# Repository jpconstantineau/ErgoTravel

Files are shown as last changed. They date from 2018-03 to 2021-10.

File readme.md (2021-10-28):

ErgoTravel
====

ErgoTravel

A split ergo 4x6 keyboard with 2 or 3 thumb keys and extra inner macro keys designed by Pierre Constantineau. [More info on the GitHub Repo](https://github.com/jpconstantineau/ErgoTravel).

**Status** The ErgoTravel is currently well developed and has the following versions:

| Version | Description |
| --- | --- |
| ErgoTravel 1.03 | Supports MX & Alps switches  |
| ErgoTravel 1.1 | Supports MX switches  |
| ErgoTravelLight 1.0 | Supports Choc Low Profile switches  |
| ErgoTravelLight 2.0 | Supports Choc Low Profile switches and has In Switch LEDs  |

Version 1.1 was created to eliminate the "Too Many Slots Additional Cost from JLCPCB"

Keyboard Maintainer: [/u/jpconstantineau](https://github.com/jpconstantineau)  

Hardware Supported: Pro Micro (ATmega32U4) 

Hardware Availability: [Group Buys](https://keyboards.jpconstantineau.com/) or order your own [yourself](OrderingInstructions.md)



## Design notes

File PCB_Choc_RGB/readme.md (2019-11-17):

2.00: initial prototype
2.01: updated location of vias and traces near standoffs. Also updated build instructions

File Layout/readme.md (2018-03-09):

ErgoTravel
====

ErgoTravel

Use the txt files to load in KLE or swillkb.

[Keyboard Layout Editor](http://www.keyboard-layout-editor.com)
[Plate Generator](http://builder.swillkb.com/)

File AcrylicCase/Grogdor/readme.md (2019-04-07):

Work in progress, currently prototyping for fit/tolerances, stackup, fasteners, manufacturing, etc.

"TENTED" layers are currently out of sync with bluemicro holes

ToDo:
- revisit hipro design, small pieces are weak and can break off, are they really needed?
- tenting is wobbly, boo
- put engrave near the top, so job doesn't have to wait/scroll all the way down to it... saves like 20sec per plate
- use "plated" lines inside "cutout" for everything, not sharp duplicate corners (but check corner @ TRRS jack for PCB clearance) - no longer relevant because we're not making internal  plates of the leftover material, however rounded corners would likely put less strain on the material
- 2ustabs engraves need to happen in one shot for proper material removal, not needlessly+time spread across workpieces; how to ensure that? - because of heat buildup for removing material, if the laser traverses the whole sheet it doesn't happen properly. Engraves are set to Y axis, so just spread the black fills across the plate as needed.
- fillet sharp outside bottom corner where hand sits - doesn't look/feel right
- *** join all polylines + overkill ***
- figure out why Corel Draw puts a red outline around the black hatch engrave for 2ustabs - just doesn't handle AutoCAD hatches, have to cleanup lines and fill color manually for .cdr file
- figure out how layers/groups/viewports work for easier viewing, exporting, etc. - really need a CAD pro for some tricks to do this easier...

ToTry:
- 6mm hipro with blind inserts
- consider 9mm mid (no bonus internal plate on this one, segment it) with optional 3mm addon or other stackups
- spread out the two tenting bolts (trrs to top? bottom to corner or at least closer?), make single tenting screw more central to balance point
- reorganize layers into nested groups to tame the chaos
- a few "yellow" surface finish cuts can be sped up "red" like inside of "cutouts" etc
- colors? something other than clear/white/smoke scraps
- experiment with "internal pcb" screws through the top plate, for strength
- experiment with segmented midlayer(s), saves significant material, easier/stronger to ship
- see how long it takes the Rabbit, what the finish/kerf/accuracy is like...
- ditch the single foot and replace with a strip of rubber/neoprene edge for flat-f/b tent
- furniture swivel/levelling feet for tenting? do these come small enough? what's the grip surface like?
- alu rod, ball one end on the lathe, trim/thread to taste, goes into nut pressed into case, polish/paint/shrink tube
- check model shop for "aluminum pillow balls" and other small suspension bits for ^
- cool crane outriggers, non-swivel, flip-out, fold out, r/a inserts, diagonal slide out
- angled acrylic? edge clip ins for tenting?
- m3 thumbscrews into the side of 9-12mm midlayer to hold legs, t-slots into segments or flip em (in a jig?) and engrave nuthole, cut bolthole
- nice long radius ark at the bottom of the pcb+case where your hand goes, or maybe just in the plate/case and some neoprene...

ToDFM:
- air assist OFF?? for cleaner edges per https://www.troteclaser.com/fileadmin/content/images/News/EN_US/2016-07-crown-trophy/Handbook-for-engravers.pdf - smoke/gas made it worse, slowing down the cut and upping the Hz helped the edge finish a lot
- figure out optimal sheet/plate/bed size, important for cut layout, production runs, colors, etc. either on the Trotec or external - consider logistics of organizing pieces, turns out tossing scraps around was easier file/cut/pack-wise than keeping track of odd pieces, making extra files, etc
- shared cutlines on sheet/plate layouts - probably only worth it if paying per laser minute, even then may not be that great with these shapes

ToDon't:
- (N/A due to 3mm layers stackup) with noticeable kerf on the 9mm single midlayer, do we want to kick the bottom layer out 0.?mm to eliminate slight edge where they meet?
- (using 2ustabs as universal plate) hipro, 1u1u
- re-import "construction" layer from previous drawing
- (there's not) revisit 1u1u hipro altho there's probably not enough space between the keys to make another/non-universal SKU worthwhile

ToDone:
- switch to MX+Alps cutouts, they're also openable!! ***
- 2U/1U Combined stabilizer hole ***
- 2U Stab Hole stepped engrave over bar, how will other stabs fit? make sure 1u1u and 2u keycaps cover clear engrave surface finish *
- separate keyswitch/1u1u/2ustab layers
- Design Mids/Bottom with Tenting Holes (as extra layer) **
- cutline ordering with colors, to spread/prevent offgassing thumps and make better use of traverse *
- change layer colors to reorder cutting per Trotec default
- re-import "PCB" layer from previous drawing
- Design Mid Layer/Bottom Plate for Wireless ErgoTravel (No TRRS connector) (as layer?) *
- wiggle reset button hole over just a wee bit
- Insert Small Bottom Plate in Mid layers **
- Insert Top Plate in Mid layers **
- ^^ check screwhole positions and size
- hipro, 2ustab *
- ^^ check keycap clearances
- try lower power+speed and/or higher Hz for cleaner edge finish *

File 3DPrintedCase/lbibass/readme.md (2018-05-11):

here's my design for a printed case for the ergotravel. Note that the design could change as I make revisions to it. I will update the names as that happens. I will also document the changes in the PR.

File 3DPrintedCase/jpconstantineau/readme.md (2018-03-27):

ErgoTravel
====

To Do:

Design of a 3D printed Case in 4 parts

Top/Bottom Left
Top/Bottom Right

Similar design to Let's Split Case [on Thingiverse](https://www.thingiverse.com/thing:2626039)

- It's angled 
- It's very close to the size of the PCB
- The back of the case protects the connectors.

Ideally generated with OpenScad (to make the design open source using free tools - just like the PCB)

Production Files to be stored in STL folder once completed so that people don't need to "compile" the design into a file that can be produced.

Note: dxf files are for reference. The orientation of the 1U thumb switches are not right

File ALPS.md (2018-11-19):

# Considerations when Using Alps-Style switches

If you're planning on putting ALPS-style switches in your ergotravel, there are a couple things you'll have to consider.

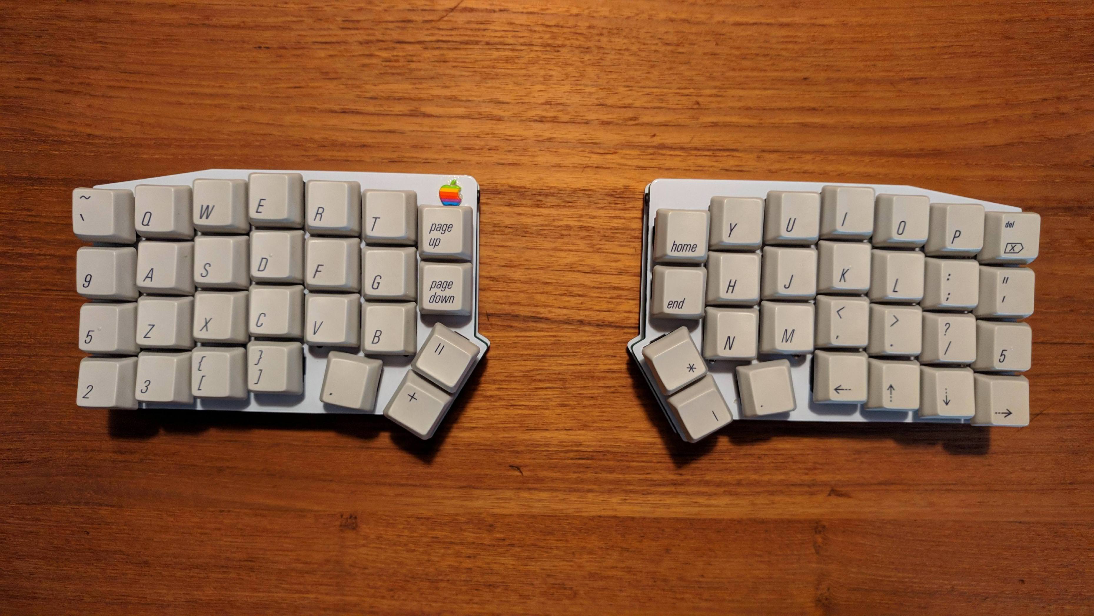
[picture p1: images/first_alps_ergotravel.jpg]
A completed Alps build.

*A completed Alps build.*

Currently, the plates only allow for 2 1u keycaps in the thumbs. As such, you won't be able to put a 2u keycap in there.

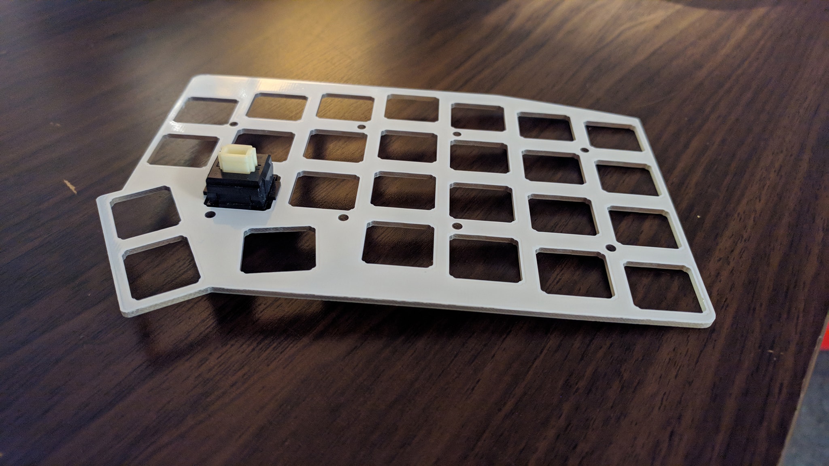
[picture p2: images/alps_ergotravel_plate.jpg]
Alps ergotravel plate.

*Alps ergotravel plate.*

Because the switches are ever-so-slightly wider than their MX counterparts, you'll have to file down the bottom left and right corners of the switches that sit on top of the ProMicro. This will allow the switch to sit flush upon the PCB. This is also true of the Iris and indeed any other keyboard that has switches right on top of the ProMicro.

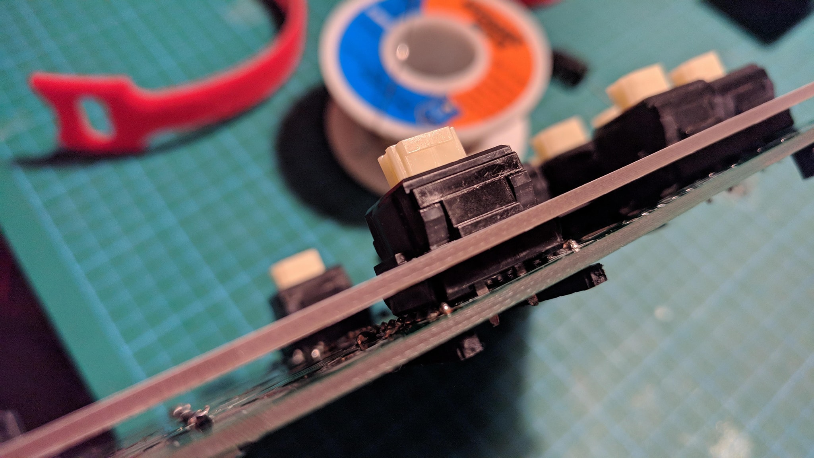
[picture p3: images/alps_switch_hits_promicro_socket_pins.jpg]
Alps switch resting upon promicro socket pins.

*Alps switch resting upon promicro socket pins.*

You may have to use similar methods to accomodate diode leads in rare occurences. Try to ensure that all switches sit flush prior to soldering them.

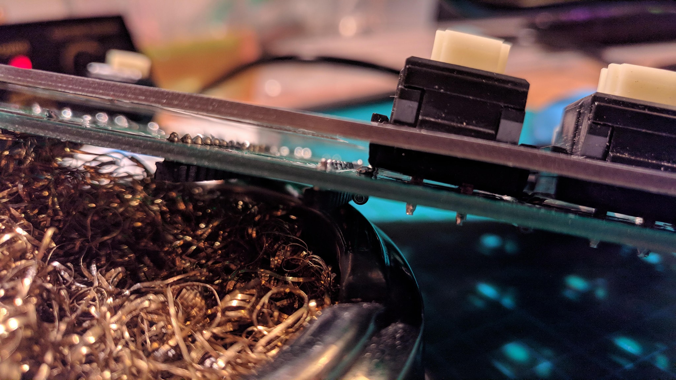
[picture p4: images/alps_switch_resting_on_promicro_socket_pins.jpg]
Alps switch resting upon diode leads.

*Alps switch resting upon diode leads.*

To do so, simply place a file on the table and run the corner of the switch along it at a 45-degree angle as pictured below.

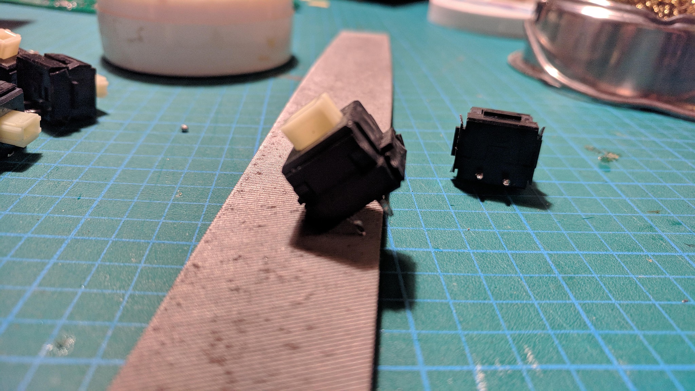
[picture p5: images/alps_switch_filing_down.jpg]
Filing down the corner of an Alps switch.


Continue with the other bottom side of the switch until it sits flush on the PCB. This doesn't take much and shouldn't go through the housing at all.

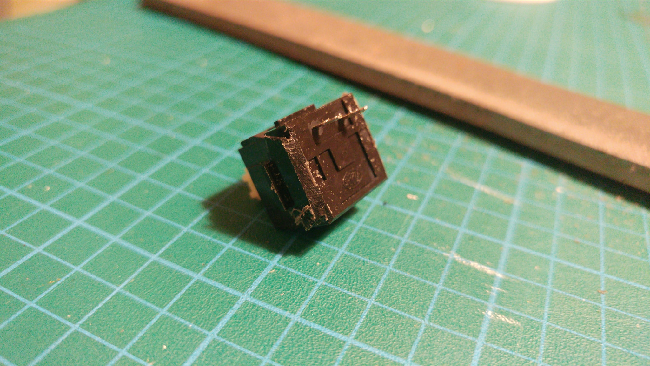
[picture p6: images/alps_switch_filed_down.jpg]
A corner of an alps switch after filing it down.


When finished, the switches should sit flush against the PCB, the filed down corners now accomodating the promicro's sockets.

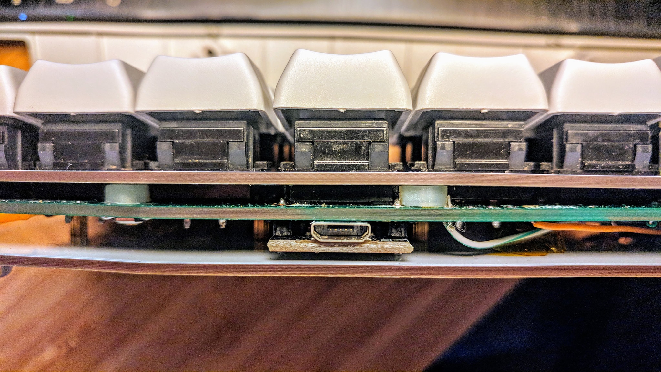
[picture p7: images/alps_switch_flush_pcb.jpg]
Alps switch sitting flush on top of promicro.

*Alps switch sitting flush on top of promicro.*

You'll also likely have to clip the leads of the switches that sit on top of the pro micro if you're using low-profile sockets or no sockets. These too may make contact with the promicro if left at their full length.

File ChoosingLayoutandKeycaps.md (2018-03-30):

# Choosing the layout of your Ergotravel

---

There are 3 options for the layout of the ErgoTravel.  They account for 4 unique configurations.

## Option 1: 2x 2U Thumb Keys

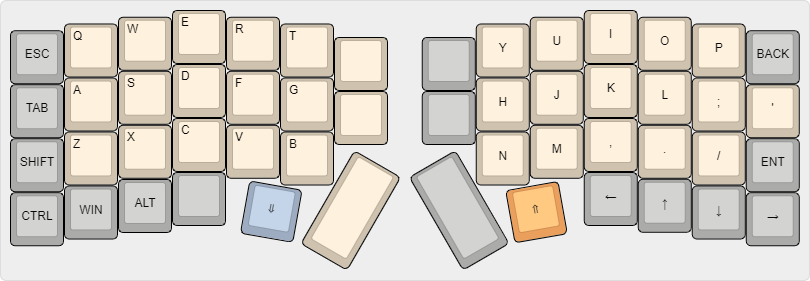
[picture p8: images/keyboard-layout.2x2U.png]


## Option 2: 1x 2U and 2x 1U Thumb Keys
With this option the 2U key will be on the left or right with the 2x 1U keys on  the other side.
Note that some Planck Keycap kits will not have enough 1U keys to support this layout.  The 4 1U macro keys on the inner columns may be left out.

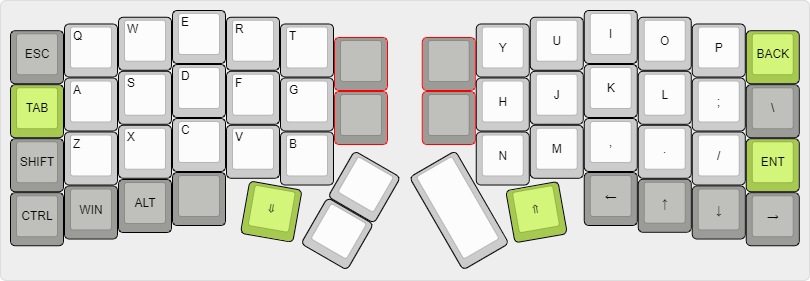
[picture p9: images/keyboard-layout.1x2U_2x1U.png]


## Option 3: 4x 1U Thumb Keys
With this option, you will only use 1U keys and will not require stabilizers. 
Note that many of the Planck Keycap kits will not have enough 1U keys to support this layout.  Only the larger kits may be able to support this layout.

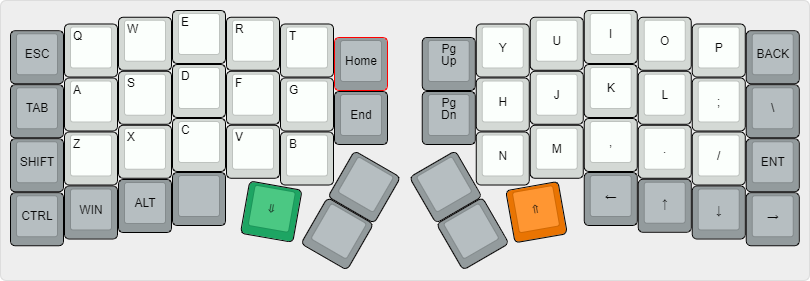
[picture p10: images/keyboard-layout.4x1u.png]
4x1u


# Choosing the keycaps for your Ergotravel

If you have pre-selected your layout, you will want to find a keycap kit that has enough keys for your layout.  Below are examples of kits that could be used for the supported layouts.  You may have to compromise on color or keycap profile.

## Option 1: 2x 2U Thumb Keys

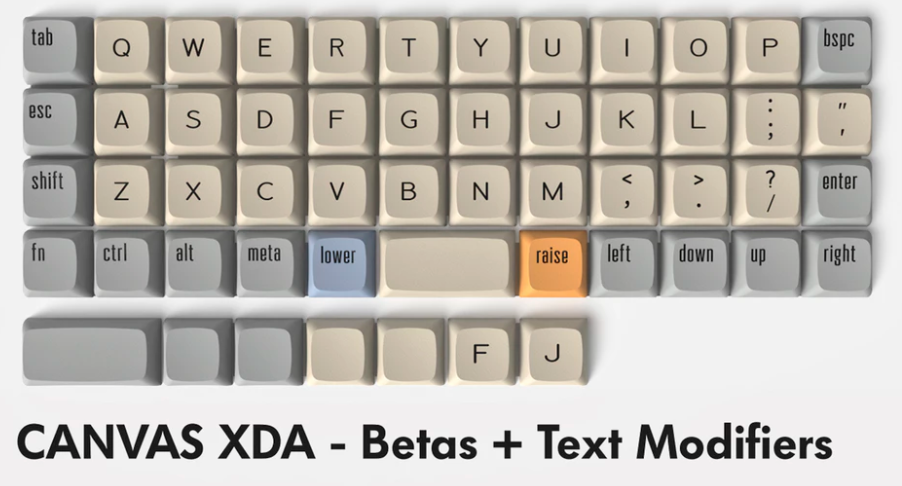
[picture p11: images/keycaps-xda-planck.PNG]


## Option 2: 1x 2U and 2x 1U Thumb Keys

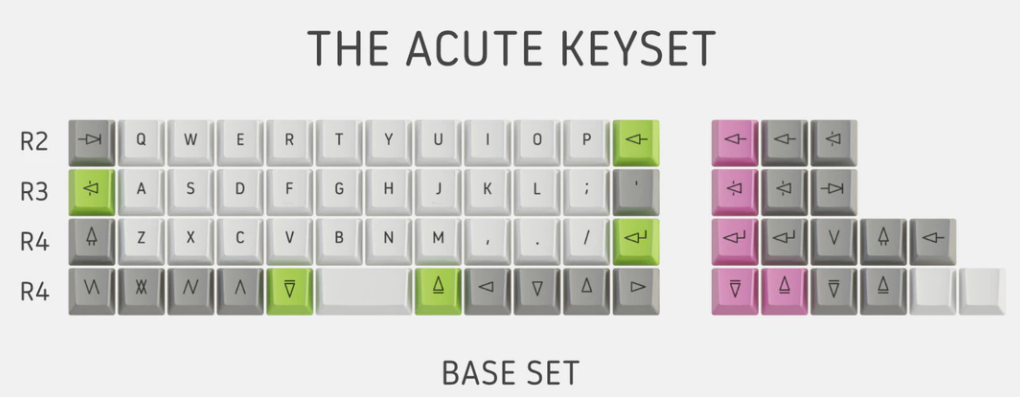
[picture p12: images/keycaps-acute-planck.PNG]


## Option 3: 4x 1U Thumb Keys

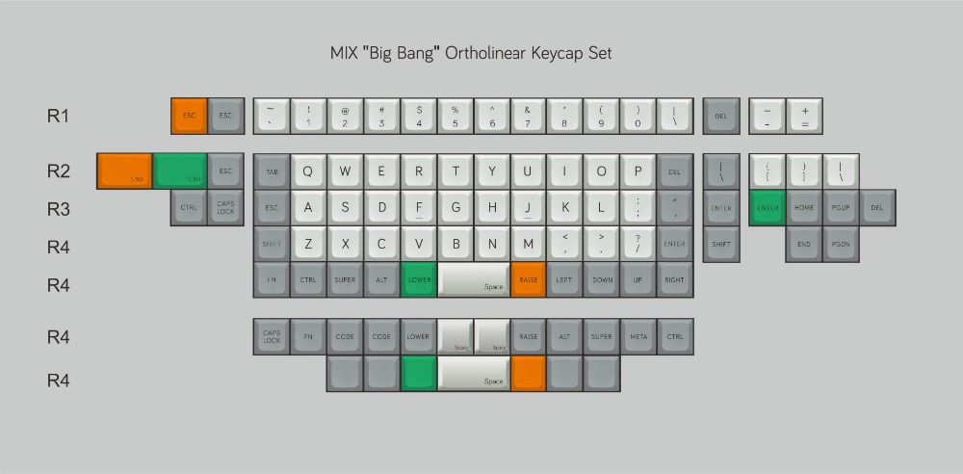
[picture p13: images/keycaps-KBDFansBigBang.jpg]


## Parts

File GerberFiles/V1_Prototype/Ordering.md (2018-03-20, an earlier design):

## Instructions on how to order these gerber files

Go to [AllPCB](https://www.allpcb.com/online_quote.html?hidLength=&hidWidth=&num=&txtSelNum=&Layersquote=2&Thicknessquote=1.6), [JLCPCB](https://jlcpcb.com/quote) or [EasyEDA](https://easyeda.com/order) and order the PCBs with the parameters shown below.
For a more comprehensive list of places where you can have the PCB manufactured, go to [PCBShopper](https://pcbshopper.com/).

When you are ready to order, you will need to enter a number of parameters to get a quote and get the PCB manufactured.
You will need yo upload the gerber files.  Some sites can read PCB dimensions from the Gerber while for others, you will need to enter it.
Choice of solder mask color (the main color of the PCB), may have a significant impact on the price of the PCB.  Green is generally the cheapest.

Quantities below will allow you to make 5 pairs with Top and Bottom Plates.  Some PCB Fab shops may ship you a few extras PCBs.

### PCB.Gerber.zip

```
94mm * 139.7mm;
Layers: 2;
PCB Thickness: 1.6mm;
PCB Qty.: 10;
PCB Color: Green;
Surface Finish: HASL;
Copper Weight: 1;
Panelized PCBs: 1
```

### TopPlate.Gerber.zip

```
150mm * 105mm;
Layers: 2;
PCB Thickness: 1.6mm;
PCB Qty.: 10;
PCB Color: Black;
Surface Finish: HASL;
Copper Weight: 1;
Panelized PCBs: 1
```

### BottomPlate.Gerber.zip

```
150mm * 105mm;
Layers: 2;
PCB Thickness: 1.6mm;
PCB Qty.: 10;
PCB Color: Black;
Surface Finish: HASL;
Copper Weight: 1;
Panelized PCBs: 1
```

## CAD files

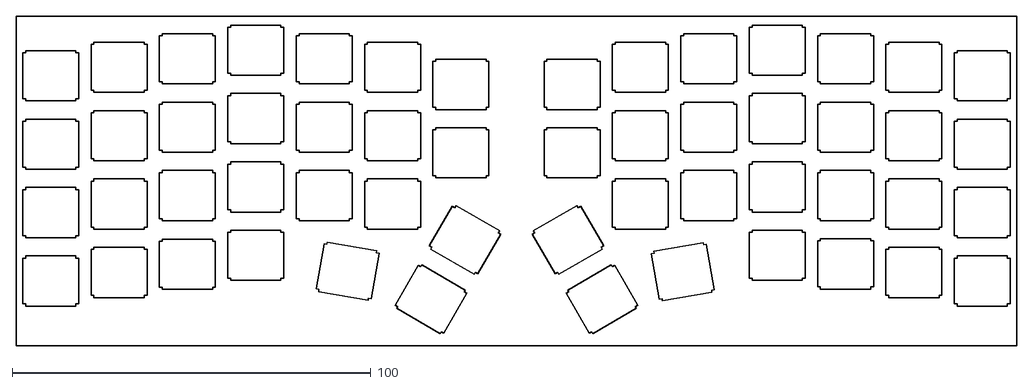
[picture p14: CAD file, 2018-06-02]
3DPrintedCase/jpconstantineau/all 1u.dxf
278.6 x 91.9

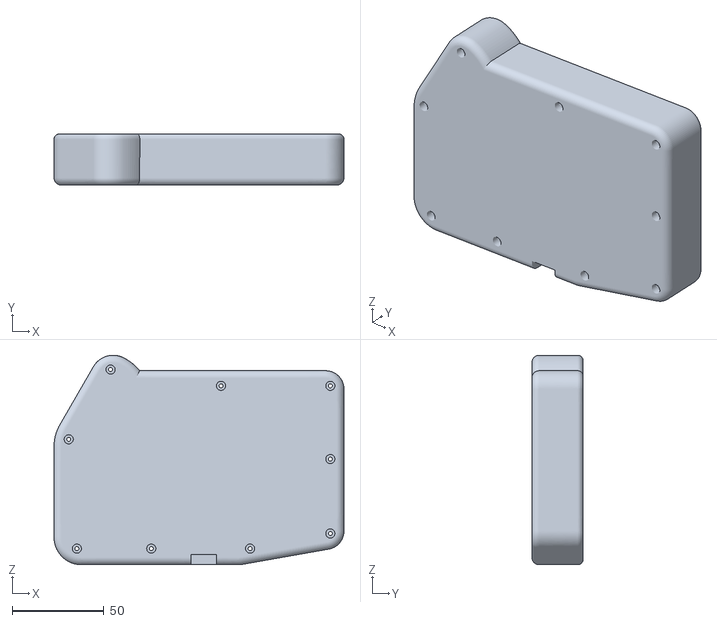
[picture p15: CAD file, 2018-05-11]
3DPrintedCase/lbibass/high_profile_right.stl
158.4 x 28.0 x 114.4

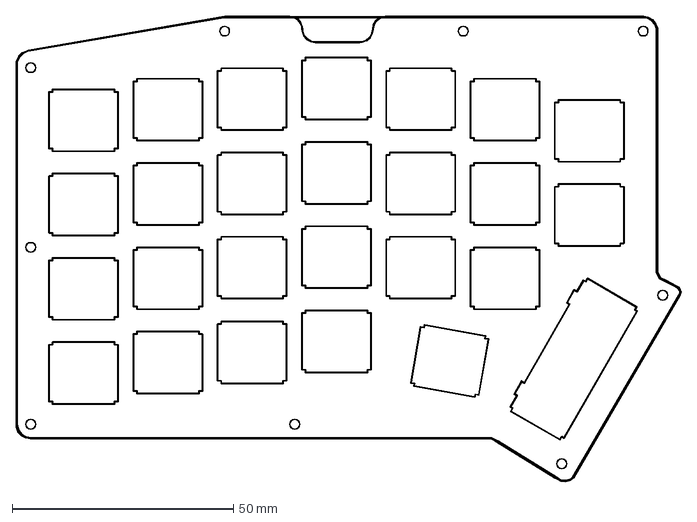
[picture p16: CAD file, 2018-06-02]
AcrylicCase/jpconstantineau/BottomPlate/BottomPlate.dxf
150.3 x 105.2 mm

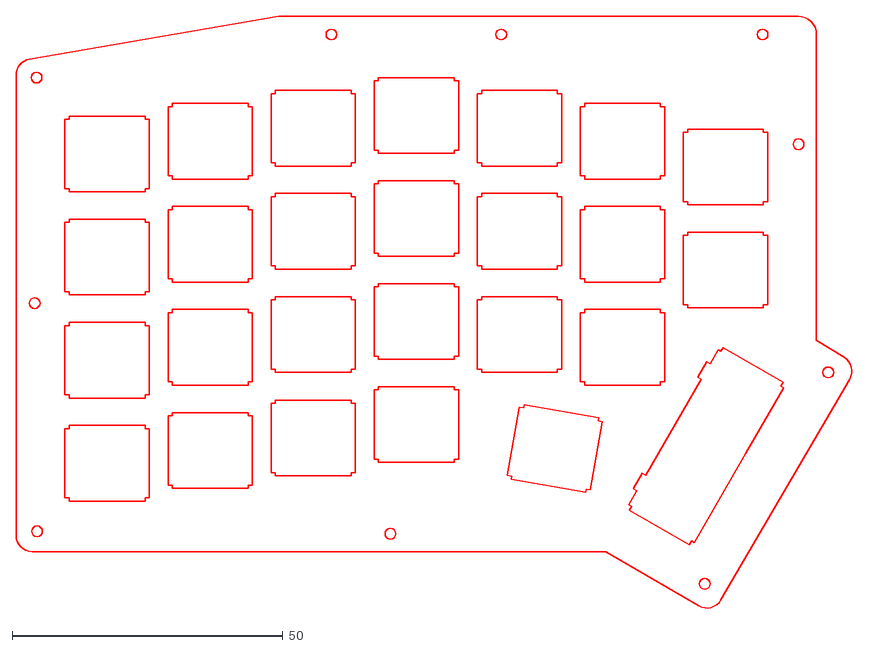
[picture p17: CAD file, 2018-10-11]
AcrylicCase/jpconstantineau/everything.dxf
154.9 x 109.4

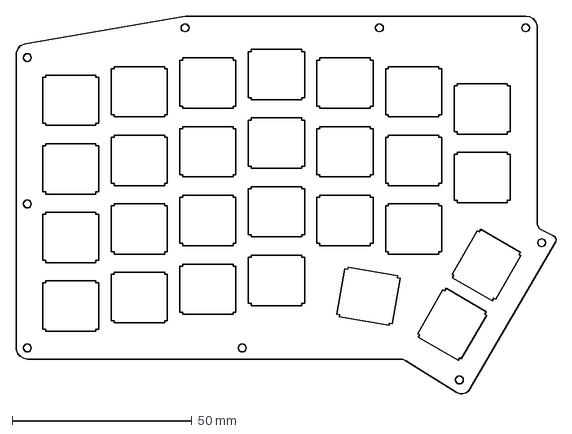
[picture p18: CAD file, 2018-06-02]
AcrylicCase/jpconstantineau/TopPlate1U/TopPlate.dxf
150.0 x 104.9 mm

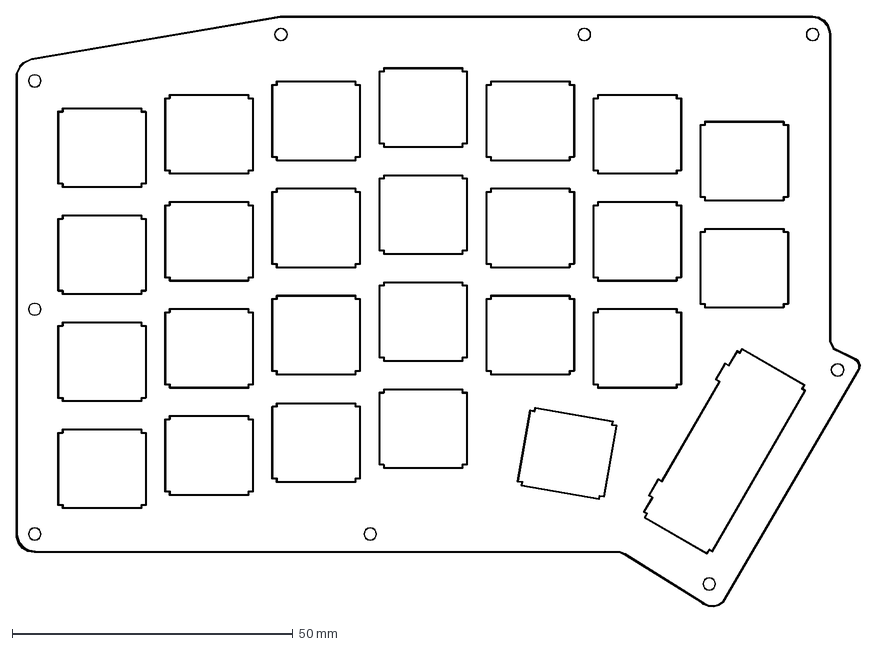
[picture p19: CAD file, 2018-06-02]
AcrylicCase/jpconstantineau/TopPlate2U/TopPlate.dxf
150.2 x 105.1 mm

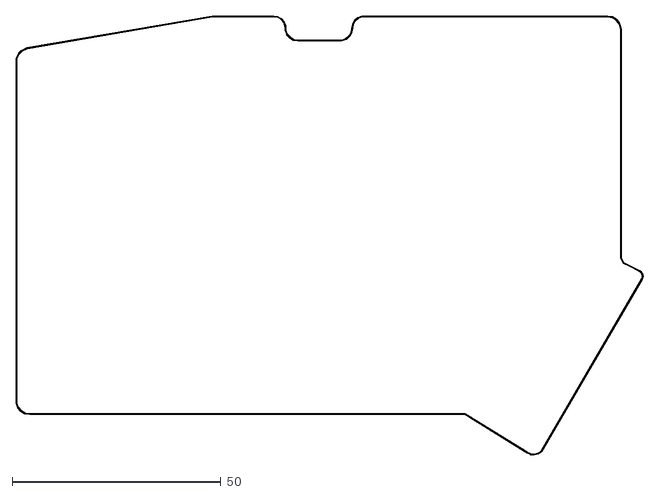
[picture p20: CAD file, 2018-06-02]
ExternalPCBCase/BottomPlate/Bottom Plate-Edge.Cuts.dxf
150.2 x 105.1

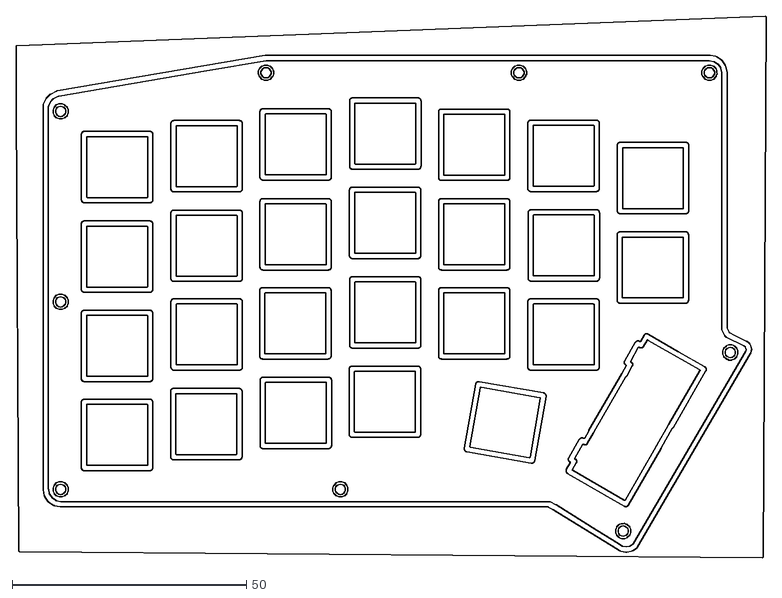
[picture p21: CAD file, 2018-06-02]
ExternalPCBCase/TopPlate1U/Top Plate-F.Cu.dxf
160.0 x 115.6

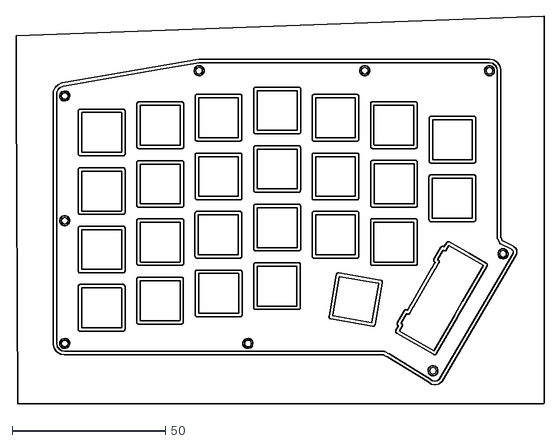
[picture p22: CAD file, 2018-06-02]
ExternalPCBCase/TopPlate2U/Top Plate-B.Cu.dxf
172.1 x 126.4

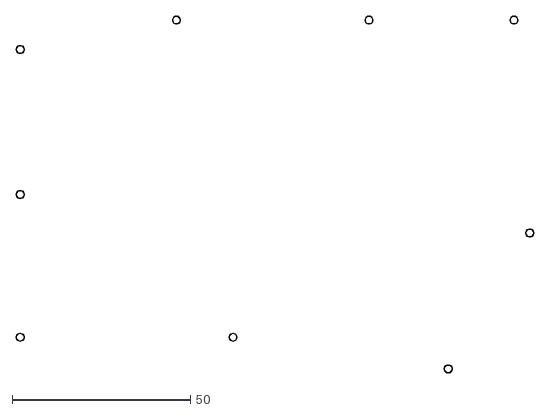
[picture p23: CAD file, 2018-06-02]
ExternalPCBCase/TopPlateCombined/Top Plate-F.Cu.dxf
145.0 x 100.0

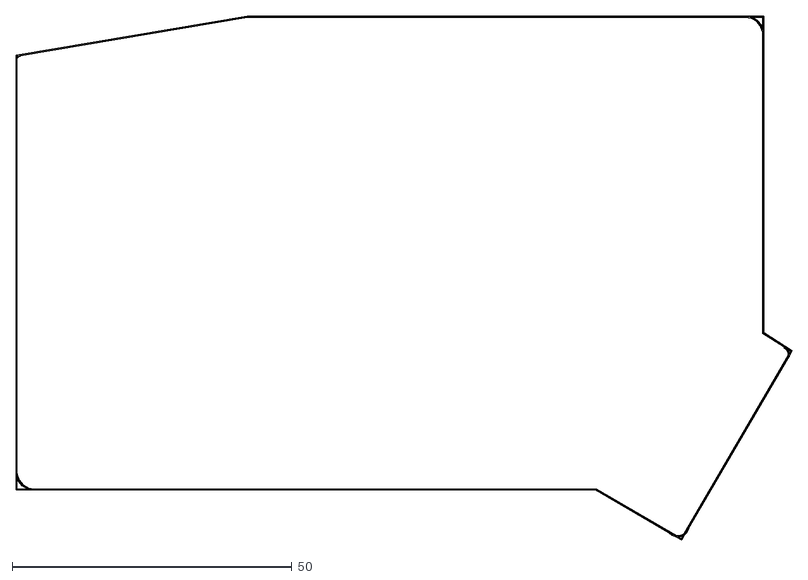
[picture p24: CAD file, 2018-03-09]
InternalPCBCase/TopPlate2U/TravelDox-Edge.Cuts.dxf
138.6 x 93.5

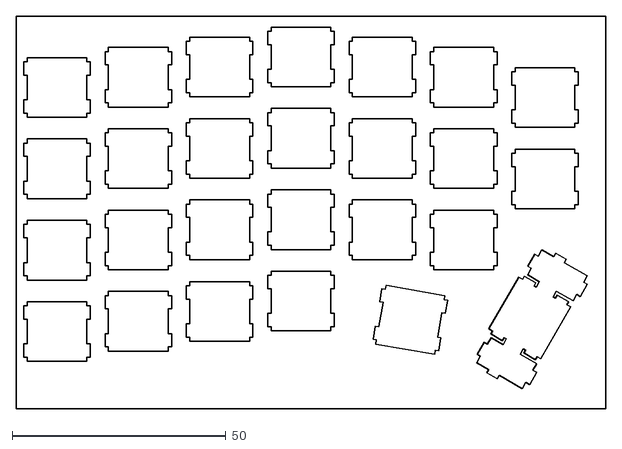
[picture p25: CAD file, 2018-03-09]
Layout/ErgoTravel_2u.dxf
138.0 x 91.9

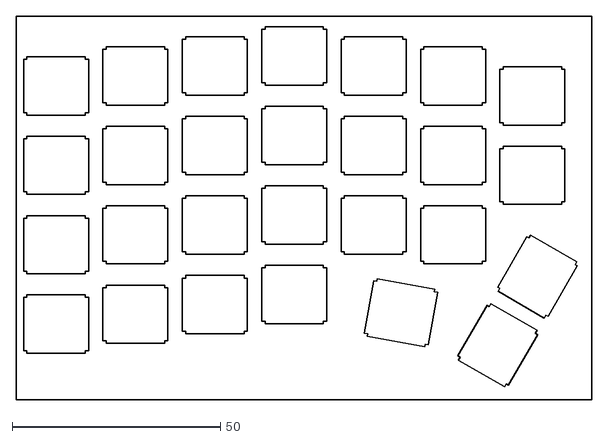
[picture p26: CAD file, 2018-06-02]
3DPrintedCase/jpconstantineau/SwillKB_1U.dxf
138.0 x 91.9

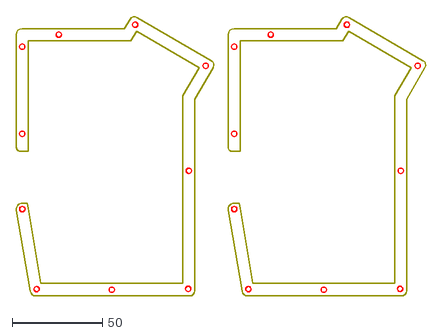
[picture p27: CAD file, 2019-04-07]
AcrylicCase/Grogdor/mids only bluemicro DFM9.dxf
226.7 x 154.9

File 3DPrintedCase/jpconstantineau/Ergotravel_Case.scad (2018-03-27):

spacingdfx=25.4*3/4;

spacing=25.4*3/4;

frontbackangle = 10;
leftrightangle = 10;
mxalps = 1;  // 0:MX 1:MXAlps

module punchMX()
{
 difference(){
  cube([20,20,20],center = true);
        
        translate([-spacingdfx,-spacingdfx,0])
        linear_extrude(height = 50, center = true, convexity = 10)
        import (file = "MX2.dxf");



 }
}

module punchMXAlps()
{
 difference(){
  cube([20,20,20],center = true);
        
        translate([-spacingdfx,-spacingdfx,0])
        linear_extrude(height = 50, center = true, convexity = 10)
        import (file = "MXAlps2.dxf");



 }
}   

translate([0*spacing,0*spacing,0])
        union()
        {

        translate ([0*spacing,0*spacing,0]) if (mxalps==1) punchMXAlps(); else punchMX(); 
        translate ([0*spacing,1*spacing,0]) if (mxalps==1) punchMXAlps(); else punchMX(); 
    translate ([0*spacing,2*spacing,0]) if (mxalps==1) punchMXAlps(); else punchMX(); 
        translate ([0*spacing,3*spacing,0]) if (mxalps==1) punchMXAlps(); else punchMX(); 
}

translate([1*spacing,0.125*spacing,0])
        union()
        {
translate ([0*spacing,0*spacing,0]) if (mxalps==1) punchMXAlps(); else punchMX(); 
translate ([0*spacing,1*spacing,0]) if (mxalps==1) punchMXAlps(); else punchMX(); 
    translate ([0*spacing,2*spacing,0]) if (mxalps==1) punchMXAlps(); else punchMX(); 
        translate ([0*spacing,3*spacing,0]) if (mxalps==1) punchMXAlps(); else punchMX(); }
        
translate([2*spacing,0.25*spacing,0])
        union()
        {
translate ([0*spacing,0*spacing,0]) if (mxalps==1) punchMXAlps(); else punchMX(); 
translate ([0*spacing,1*spacing,0]) if (mxalps==1) punchMXAlps(); else punchMX(); 
    translate ([0*spacing,2*spacing,0]) if (mxalps==1) punchMXAlps(); else punchMX(); 
        translate ([0*spacing,3*spacing,0]) if (mxalps==1) punchMXAlps(); else punchMX(); }        

translate([3*spacing,0.375*spacing,0])
        union()
        {
translate ([0*spacing,0*spacing,0]) if (mxalps==1) punchMXAlps(); else punchMX(); 
translate ([0*spacing,1*spacing,0]) if (mxalps==1) punchMXAlps(); else punchMX(); 
    translate ([0*spacing,2*spacing,0]) if (mxalps==1) punchMXAlps(); else punchMX(); 
        translate ([0*spacing,3*spacing,0]) if (mxalps==1) punchMXAlps(); else punchMX(); }
        
translate([4*spacing,0.25*spacing,0])
        union()
        {
translate ([0*spacing,0*spacing,0]) if (mxalps==1) punchMXAlps(); else punchMX(); 
translate ([0*spacing,1*spacing,0]) if (mxalps==1) punchMXAlps(); else punchMX(); 
    translate ([0*spacing,2*spacing,0]) if (mxalps==1) punchMXAlps(); else punchMX(); 
        translate ([0*spacing,3*spacing,0]) if (mxalps==1) punchMXAlps(); else punchMX(); }   
        
translate([5*spacing,0.125*spacing,0])
        union()
        {
translate ([0*spacing,0*spacing,0]) if (mxalps==1) punchMXAlps(); else punchMX(); 
translate ([0*spacing,1*spacing,0]) if (mxalps==1) punchMXAlps(); else punchMX(); 
    translate ([0*spacing,2*spacing,0]) if (mxalps==1) punchMXAlps(); else punchMX(); 
        translate ([0*spacing,3*spacing,0]) if (mxalps==1) punchMXAlps(); else punchMX(); }                        
        translate([6*spacing,0*spacing,0])
        union()
        {
translate ([0*spacing,0*spacing,0]) if (mxalps==1) punchMXAlps(); else punchMX(); 
translate ([0*spacing,1*spacing,0]) if (mxalps==1) punchMXAlps(); else punchMX(); 
    translate ([0*spacing,2*spacing,0]) if (mxalps==1) punchMXAlps(); else punchMX(); 
        translate ([0*spacing,3*spacing,0]) if (mxalps==1) punchMXAlps(); else punchMX(); }                        

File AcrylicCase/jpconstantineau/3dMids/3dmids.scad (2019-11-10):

//translate([-4,-229,0]) import("mids only DFM8.dxf");

deltax=96.5566-55.7747;
deltay=150.2566-126.4705;
angle = 90+atan(deltax/deltay)+180;
//x =(55.4645+90.1214)/2;  //inside coordinates
//y =(142.8004+122.5833)/2; inside coordinates

positionfactor = 0.2;
leg3x =55.7747+deltax*positionfactor; 
leg3y =150.2566-deltay*positionfactor;
leg3angle = angle;

leg2x = 12.3291+9/2+2;
leg2y = -3.793;
leg2angle = 180;

leg1x = 12.3291+9/2+2; 
leg1y = 137.5178+6.6129;
leg1angle = 0;

module nut_trap (
        w = 5.5,
        h = 3
        )
{
        cylinder(r = w / 2 / cos(180 / 6) + 0.05, h=h, $fn=6);
} 


module punch(t)
{
    translate ([0,0,-1])
    {
      cylinder(h=3,d=9,center=false, $fn=100);
      cylinder(h=10,d=3,center=false, $fn=100);
    }
    translate ([0,0,(t-2)])
    {
        nut_trap();
    }
}

// 3mm Standoff
module standoff(x, y)
{
    color("silver",1)
    translate([x,y,0]){
        difference(){
            cylinder(h=12,d=3,center=false, $fn=100);
            translate([0,0,-1]){cylinder(h=14,d=1.5,center=false, $fn=100);}
        }
    }
}

module smallsection()
{
// small section
linear_extrude(height = 12)
{
  difference()
  {
    union() // this is the material itself
    {
        // polygon without the rounded corners
      polygon(points=[[-4.6081,76.1921],[-4.6081,134.1734],[-11.2970,134.1734],[-11.2970,78.7865],[-8.7026,76.1921]]);
        // rounded corners
      translate([-7.9526,134.1734,0])circle(d=6.6889, $fn=100);
      translate([-8.7026,78.7865,0])circle(r=2.5944, $fn=100);
    }
    union() // punch though the standoffs
    {
      translate([-7.9526,134.1734,0])circle(d=3, $fn=100);
      translate([-7.9526,85.8609,0])circle(d=3, $fn=100);
    }
  }
}

}

module bigsection()
{
difference()
{
// Big section
linear_extrude(height = 12)
{
  difference()
  {
    union() // this is the material itself
    {
        // polygon without the rounded corners
      polygon(points=[[-8.7025,64.1856],
        [-4.6078,64.1749],
        [-4.6078,44.8376],
        [2.3759,3.0928],
        [81.0135,3.0928],
        [81.0135,106.9705],
        [90.1214,122.5833],
        [55.4645,142.8004],
        [52.1630,137.5178],
        [9.5226,137.5178],
        [9.5226,141.3243],
        [12.3291,144.1307],
        [48.5166,144.1307],
        [51.7192,149.2551],
        [55.7747,150.2566],
        [96.5566,126.4705],
        [97.6364,122.3674],
        [87.6030,105.1681],
        [87.6030,-0.7993],
        [84.6030,-3.7993],
        [-0.4420,-3.7993],
        [-3.3989,-1.3062],
        [-11.2970,44.7657],
        [-11.2970,61.5976]]);
        // rounded corners
      translate([-0.4420,-0.7993,0])circle(r=3, $fn=100);
      translate([84.6030,-0.7993,0])circle(r=3, $fn=100);
      translate([95.0451,123.8791,0])circle(r=3, $fn=100);
      translate([54.2632,147.6651,0])circle(r=3, $fn=100);
      translate([-8.7025,61.5911,0])circle(r=2.5944, $fn=100);
      translate([12.3291,141.3243,0])circle(r=2.8065, $fn=100);
    }
    union() // punch though the standoffs
    {
      translate([0,0,0])circle(d=3, $fn=100);
      translate([41.6947,-0.3532,0])circle(d=3, $fn=100);
      translate([83.8689,0.0861,0])circle(d=3, $fn=100);
      translate([-7.9521,54.5063,0])circle(d=3, $fn=100);
      translate([84.3083,65.4032,0])circle(d=3, $fn=100);
      translate([12.3291,140.8243,0])circle(d=3, $fn=100);
      translate([54.5043,146.3007,0])circle(d=3, $fn=100);
      translate([93.5762,123.4925,0])circle(d=3, $fn=100);
        
    }
  }
}
       translate([leg1x,leg1y,6])
            rotate([90,0,leg1angle])
            {punch(6.6129);} 
            
                   translate([leg2x,leg2y,6])
            rotate([90,0,leg2angle])
            {punch(6.6129);} 
                      translate([leg3x,leg3y,6])
            rotate([90,0,leg3angle])
            {punch(6.6129);} 

}

}





module insertstandoffs()
{
    
    // small section
standoff(-7.9526,85.8609);
standoff(-7.9526,134.1734);

// big section
standoff(0,0);
standoff(41.6947,-0.3532);
standoff(83.8689,0.0861);
standoff(-7.9521,54.5063);
standoff(84.3083,65.4032);
standoff(12.3291,140.8243);
standoff(54.5043,146.3007);
standoff(93.5762,123.4925);
}


module leg()
{
    rotate([90,180,180])
    translate([0,0,-8])
    difference()
    {
    union(){
        cylinder(h=10,d=10,center=false, $fn=100);
        translate([-4,0,0])cube([8,45,6]);
        translate([0,45,3])sphere(d=10, $fn=100);
      }
    union()
     {
         translate([0,0,-1]){cylinder(h=12,d=3,center=false, $fn=100);}
         translate([0,0,-1]){cylinder(h=4,d=7,center=false, $fn=100);}
     } 
    }
    
}



//insertstandoffs();
//smallsection();
bigsection();
pivot1 = 45;
pivot2 = 45;
pivot3 = 75;
       translate([leg1x,leg1y,6])
            rotate([180,180+pivot1,leg1angle])leg();

       translate([leg2x,leg2y,6])
            rotate([180,180-pivot2,leg2angle])leg();

       translate([leg3x,leg3y,6])
            rotate([180,180-pivot3,leg3angle])leg();

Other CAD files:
3DPrintedCase/lbibass/high_profile.stl
AcrylicCase/jpconstantineau/3dMids/3dmids_prototype_3.stl
ExternalPCBCase/BottomPlate/Bottom Plate-F.Cu.dxf
AcrylicCase/jpconstantineau/3dMids/3dmids_back.scad
AcrylicCase/jpconstantineau/3dMids/3dmids_prototype.scad
3DPrintedCase/jpconstantineau/1UMX.dxf
3DPrintedCase/jpconstantineau/1UMXApls.dxf
3DPrintedCase/jpconstantineau/2UMX.dxf
3DPrintedCase/jpconstantineau/2UMXAlps.dxf
3DPrintedCase/jpconstantineau/MX2.dxf
3DPrintedCase/jpconstantineau/MXAlps.dxf
3DPrintedCase/jpconstantineau/MXAlps2.dxf
3DPrintedCase/jpconstantineau/MxApls10degree.dxf
3DPrintedCase/jpconstantineau/mxalps2u30degree.dxf
3DPrintedCase/jpconstantineau/mxapls30degree.dxf
3DPrintedCase/lbibass/high_profile_left.stl
3DPrintedCase/lbibass/low_profile_left.stl
3DPrintedCase/lbibass/low_profile_right.stl
AcrylicCase/Grogdor/bottoms only DFM8.dxf
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

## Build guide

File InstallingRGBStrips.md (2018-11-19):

## Instructions on how to install RGB LED Strips as RGB underglow

## Software Changes
From a software point of view, make sure you enable the RGB features of the firmware as well as have the keycodes to change the RGB modes on one of your layers.

Update firmware to enable RGB underglow: the  `rules.mk` file must contains the following line:

```
RGBLIGHT_ENABLE = yes
```

To control the RGB underglow see the QMK [feature documentation](https://github.com/qmk/qmk_firmware/blob/master/docs/feature_rgblight.md)

There are a few options on how you can install the RGB strips.

## Hardware Changes: Option 1: RGB Strips at the Bottom of PCB

1. Decide which half will be your master.  The master will use the DI pin on the header next to the pro micro. VCC and GND on that same header will also be used.

### Master Half

2. Wire from the TX pad on the PCB to Din pad of the LED strip.  
3. Wire from the GND on the PCB to the GND on the LED strip.
4. Wire from the VCC on the PCB to the +5V on the LED strip.
5. At the other end of the LED strip, wire from DO to the extra data pad on the PCB (resistor next to TRRS connector). 

* Make sure you don't use the resistors; I2C is not yet compatible with RGB underglow. Also make sure you haven't jumpered/soldered the I2C jumper.

When you're done with the master half, it should look like this. With less kapton tape.

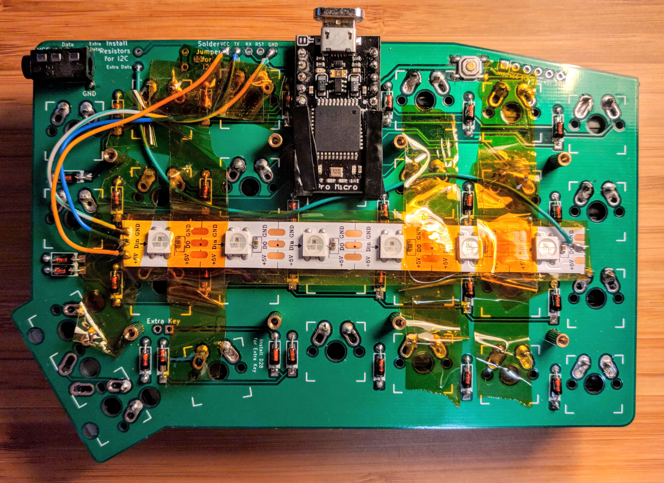
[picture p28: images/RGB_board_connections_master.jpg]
This is what the underside of the MASTER half should look like.

*This is what the underside of the MASTER half should look like*

### Slave Half

6. On the slave half, the RGB data will appear on the same extra data pin on the resistor pad. This pin will go to the Din pad of the strip.
7. Wire VCC and GND from the header next to the pro micro to the VCC and GND pads of the led strip.
8. The Do pad of the slave RGB strip will not be connected anywhere.

When you're done with the slave half, it should look like this. 

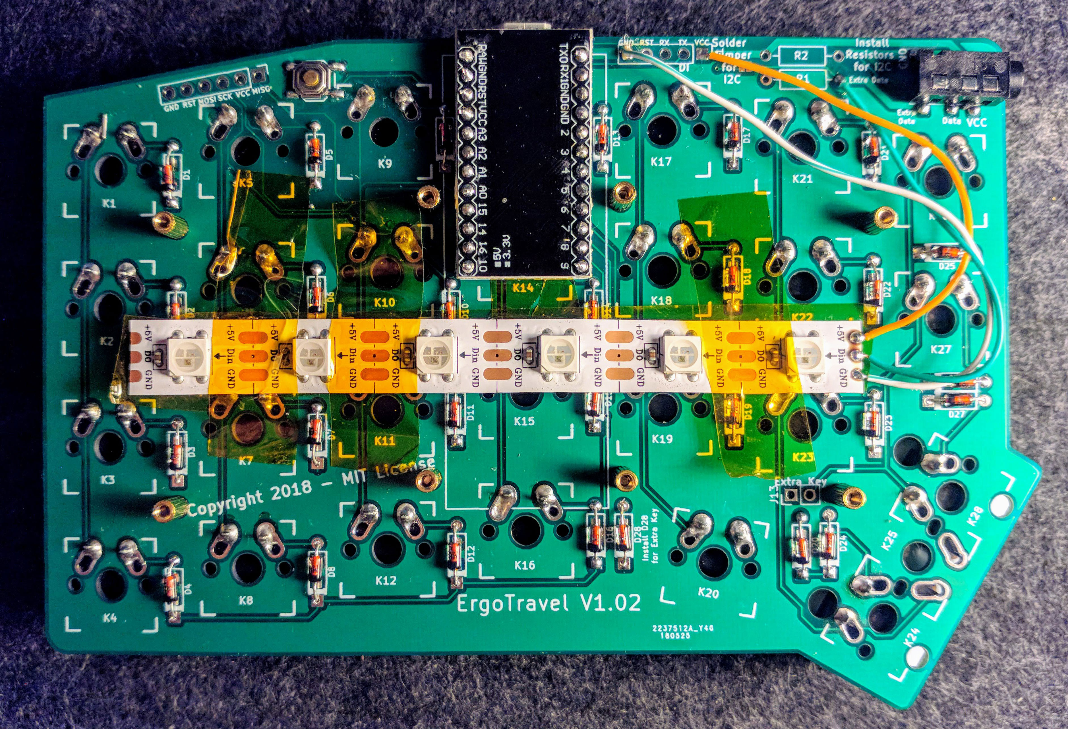
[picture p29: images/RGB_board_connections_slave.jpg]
This is what the underside of the SLAVE half should look like.

*This is what the underside of the SLAVE half should look like*

This should complete the hardware assembly.

## Hardware Changes: Option  2: RGB Strips at the Bottom of Bottom Plate - using Dupont Connectors

First, check that you have all required parts:

- 14 RGB LEDs (e.g. from WS2812/ SK6812 LED strips)
- rectangular header connectors (e.g. [PRPC040SBAN-M71RC](https://www.digikey.ca/product-detail/en/sullins-connector-solutions/PRPC040SBAN-M71RC/S1111EC-40-ND/2775294))  
  these need to be broken into 3 pieces, 2x 5 pins and 2x 1 pin
- 4x female header connectors to attach to your LED strips. Later these will be cut in half, we need 7 halves

The connectors are only required if you want to be able to detach the RGB strip, which can be useful if you need to work on the PCB after you've completed soldering.   The below images assume you're using the left side of the keyboard to control your RGB strip.

Please make sure you don't use the resistors; I2C is not yet compatible with RGB underglow. Also make sure you don't have jumpered/soldered the I2C jumper.

---

1. Solder all rectangular connectors onto both halves.
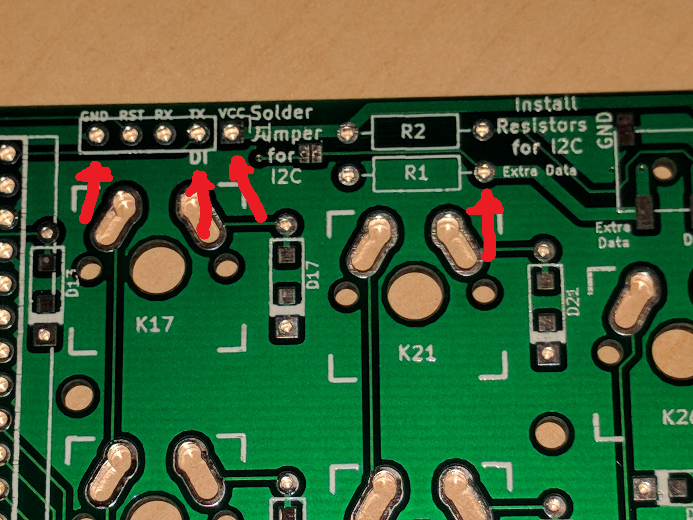
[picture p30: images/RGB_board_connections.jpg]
connections_board

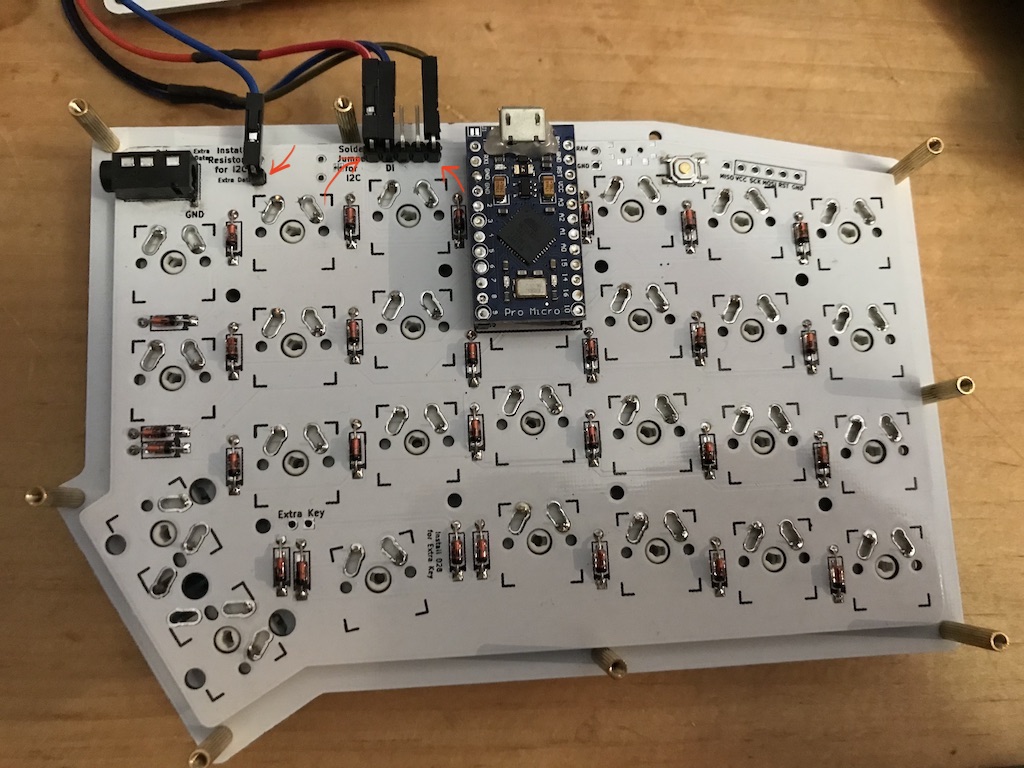
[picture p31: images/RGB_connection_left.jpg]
Back of left hand:   
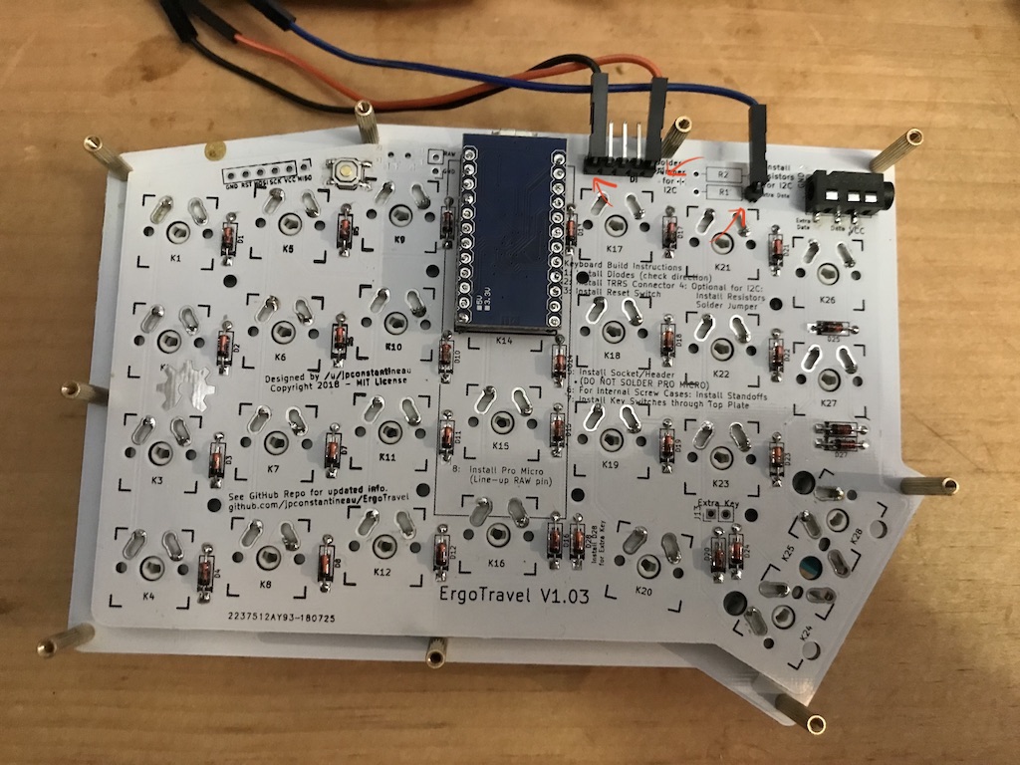
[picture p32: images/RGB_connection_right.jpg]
Back of right hand: 

2. Cut female header connectors in half to prepare them to be attached to the LED strips:
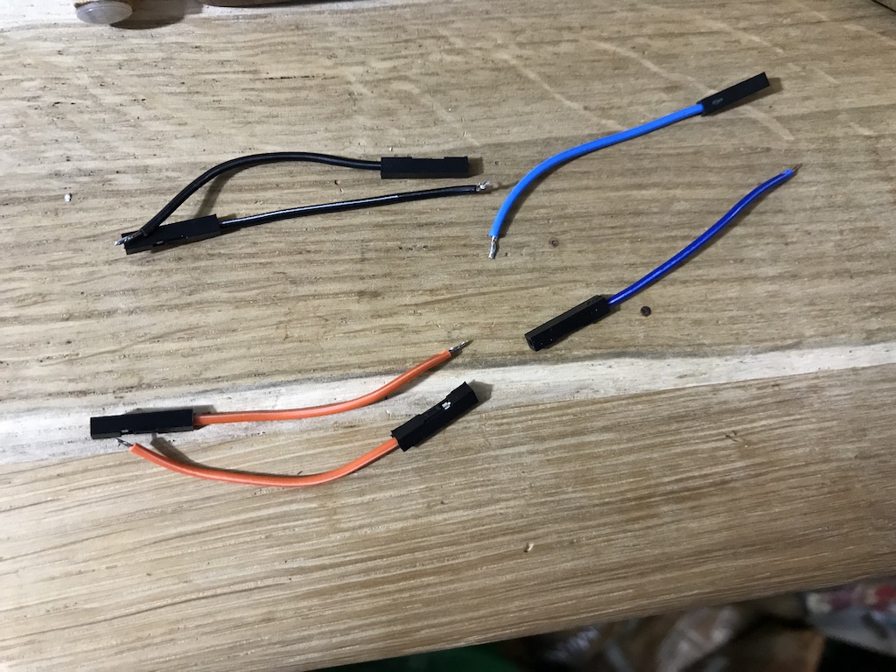
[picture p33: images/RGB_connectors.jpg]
female_connectors


3. Wire the header connectors on both RGB strips: black for GND, red for VCC, blue for data
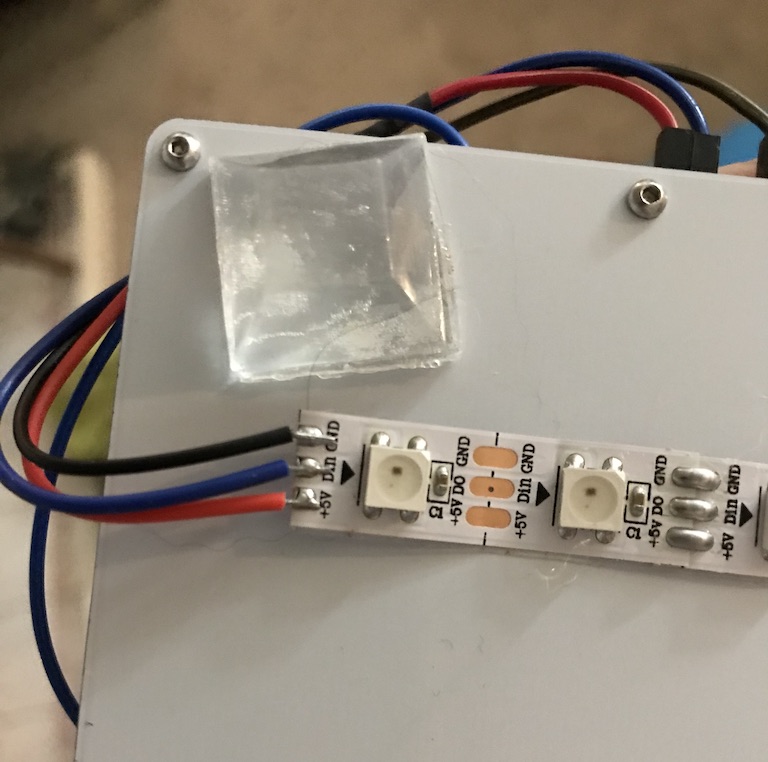
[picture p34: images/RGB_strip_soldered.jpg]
connections_strip_soldered


4. on one RGB strip, wire a header connector on the other side of the RGB strip to Do.

5. Attach female and male header connectors: Attach VCC, GND and Di on the left side, as well as Do to the single extra pin.
On the right side, Attach VCC and GND, and Di from the single extra pin.

Back of left hand: soldered_header_connectors  
Back of right hand: soldered_header_connectors

This should complete the hardware assembly.

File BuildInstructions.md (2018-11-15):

# ErgoTravel Build Instructions

---

## Review your parts

### Electronic Parts List

- [ ] 2 PCBs
- [ ] 2 5V/16MHz Pro Micros
- [ ] 2 Sockets (Note of the socket height. This will dictate what standoffs height you can use)
- [ ] 2 4.7k resistors. Only Through Hole is supported. (Optional if you want to use I2C)
- [ ] 2 surface mount TRRS Jacks (PJ-320D-A)
- [ ] 2 surface mount reset switches (switch 5.25.21.5 250gf Copper head)
- [ ] 54 1N4148 Diodes. Through Hole and SMD supported
- [ ] 1 TRRS Cable

### Optional: For RGB Underglow

- [ ] 2 WS2812 Strips

### Option 1: PCB Sandwich Case Parts List - External Screw Design

- [ ] 2 Top PCB Plates
- [ ] 2 Bottom PCB Plates
- [ ] 36 M2x4mm screws (18 per side)
- [ ] 18 M2x12mm standoffs (9 per side) (or M2x14mm for tall sockets)

### Option 2: PCB Sandwich Case Parts List - Internal Screw Design

- [ ] 2 Top PCB Plates
- [ ] 2 Bottom PCB Plates
- [ ] 32 M2x4mm screws (16 per side)
- [ ] 16 M2x8mm standoffs (8 per side) (or M2x10mm for tall sockets)

### Option 3: PCB Mount Case Parts List

- [ ] 4 PCBs (same PCBs will be used for Bottom Plates - 2 per side)
- [ ] 32 M2x4mm screws (16 per side)
- [ ] 16 M2x8mm standoffs (8 per side) (or M2x10mm for tall sockets)

### Option 4: 3D Printed Case Parts List (3D Printed Case not available yet)

- [ ] Left Case Top
- [ ] Left Case Bottom
- [ ] Right Case Top
- [ ] Right Case Bottom

### Option 5: Acrylic Case Parts List (Acrylic Case Designed for use with the Pro Micro)

- [ ] 2 Left Top
- [ ] 1 Left Switch Plate: Note the engraving around the 2u thumb hole for the stabilizer wire
- [ ] 4 Left Mid Insert
- [ ] 1 Left Bottom
- [ ] 2 Right Top
- [ ] 1 Right Switch Plate: Note the engraving around the 2u thumb hole for the stabilizer wire
- [ ] 4 Right Mid Insert
- [ ] Right Bottom
- [ ] 20 M2x12 standoffs (10 per side)
- [ ] 20 M2x6 screws (10 per side - for the bottom)
- [ ] 20 M2x12 screws (10 per side - for the top)

### Switches and stabilizers

The number of switches and stabilizers depends on the desired configuration for the thumb switches.

| Configuration | Switches | 2U Cherry Stabilizer |
| :---: | :---: | :---: |
| 4x1U  |  54 |  0  |
| 2x1U + 1x2U  |  53 |  1  |
| 2x2U  |  52 |  2  |

---

## Prepare PCBs and Install Components

### Step 1: Place PCBs face up with thumbs facing inward.

To avoid building two left or two right halves, place the PCBs side by side with the thumbs facing toward each other.

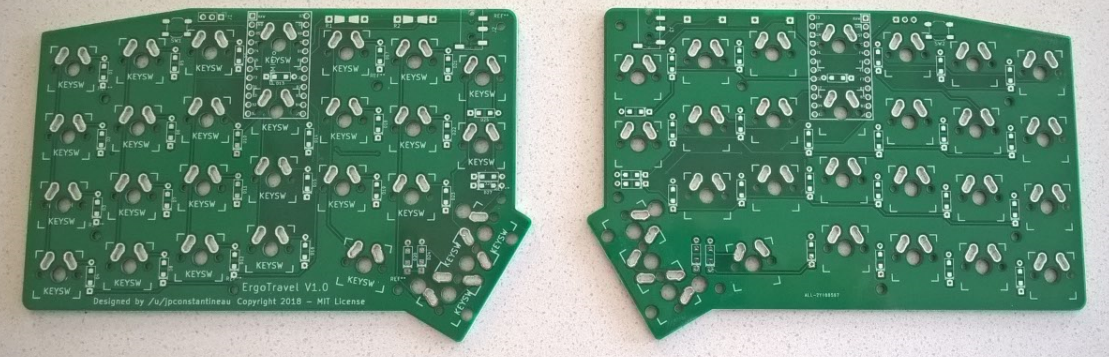
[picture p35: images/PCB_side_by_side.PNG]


### Step 2: Decide which half will be the master.

The Master half will be connected to the USB port.  This will decide where we install the I2C resistors. 
Note: In the end, it doesn't matter much if you have the resistors on the slave.

Divide the components in two halves and keep with each PCBs.
Put the 2 resistors with the master half.

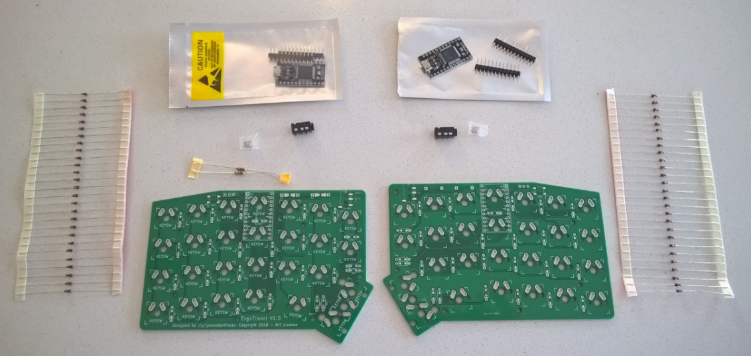
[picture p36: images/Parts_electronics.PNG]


Note: Unlike some other keyboards, there are no jumpers to configure for the left or right halves.

### Step 3: Install the diodes

#### Through hole diodes

Install diodes on **bottom side** of the board. On each half of the board, the diode beneath the pro micro will need to be installed on the **top side** of the board.  For V1.01, there is no longer a diode under the pro micro.

Use a straight edge to bend the diodes prior to installing them on the board.

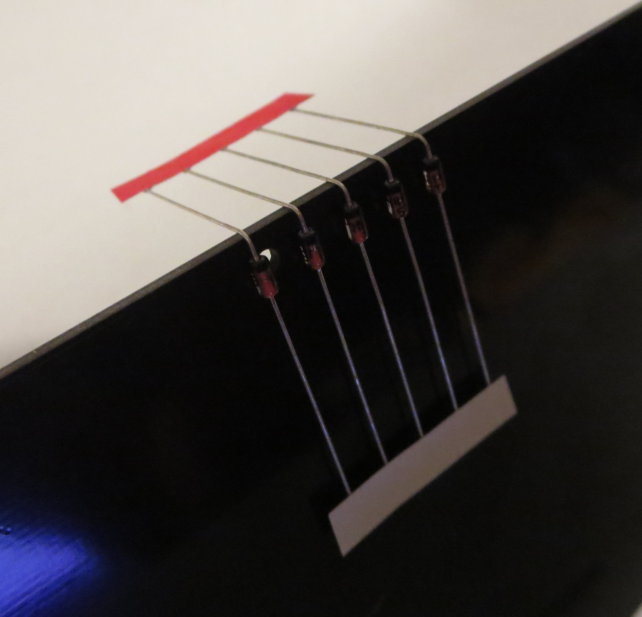
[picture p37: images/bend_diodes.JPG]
bend diodes


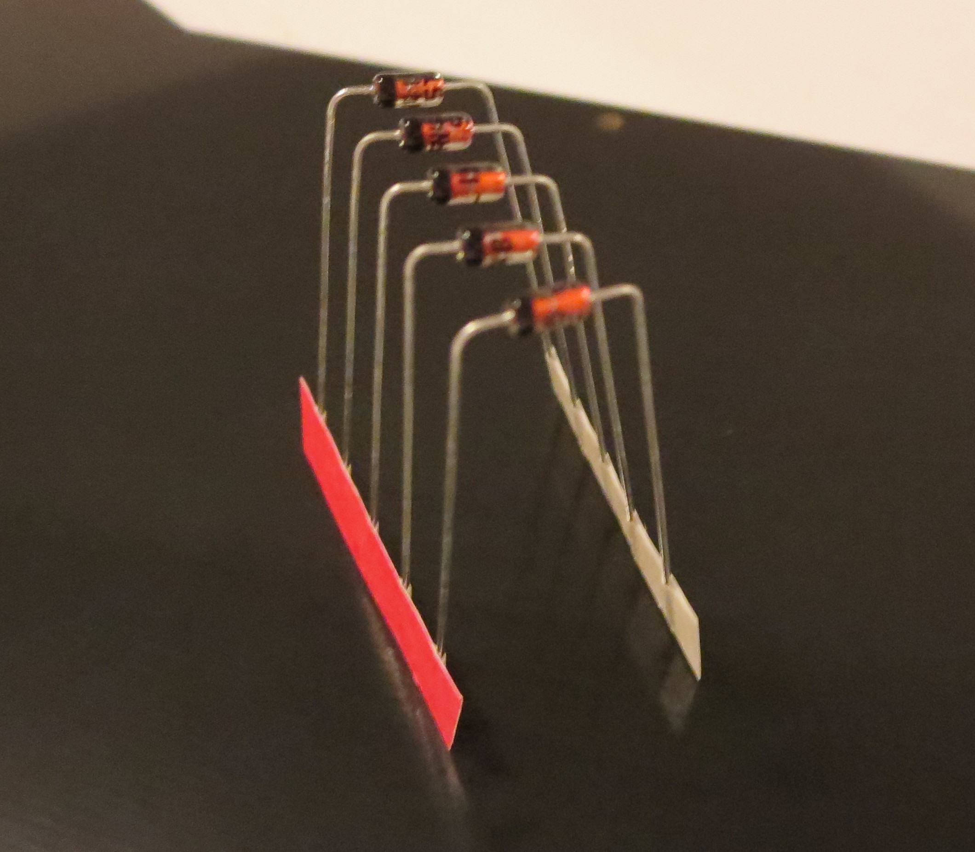
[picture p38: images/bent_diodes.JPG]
bend diodes


Black line on the diode lines up with the square pad and white line on the PCB silkscreen, bend the legs and push it through.

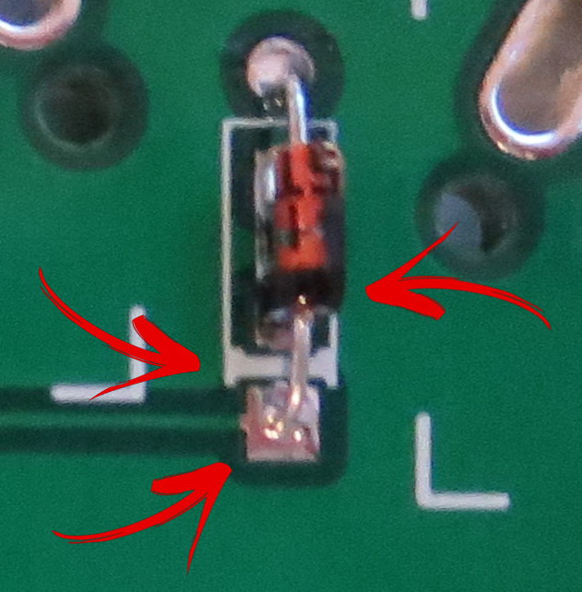
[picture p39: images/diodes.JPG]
diodes


Bands must match the bands on the silkscreen and the square pads.

Diodes ready to be installed on the left half. After inserting both legs into the PCB, bend the legs outward to keep the diodes in place when soldering.

Top view:

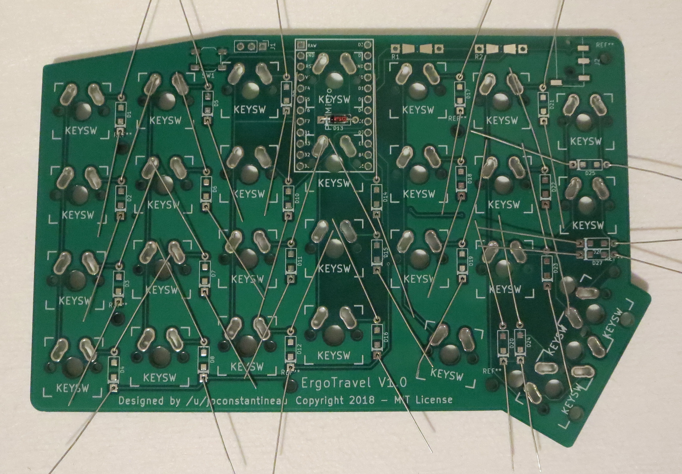
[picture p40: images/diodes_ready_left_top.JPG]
diodes left half top view


(Only applies to the V1.01 version) The diode beneath the pro micro will need to be placed on top of the PCB so that it does not come in contact with the pro micro.  

Bottom view:

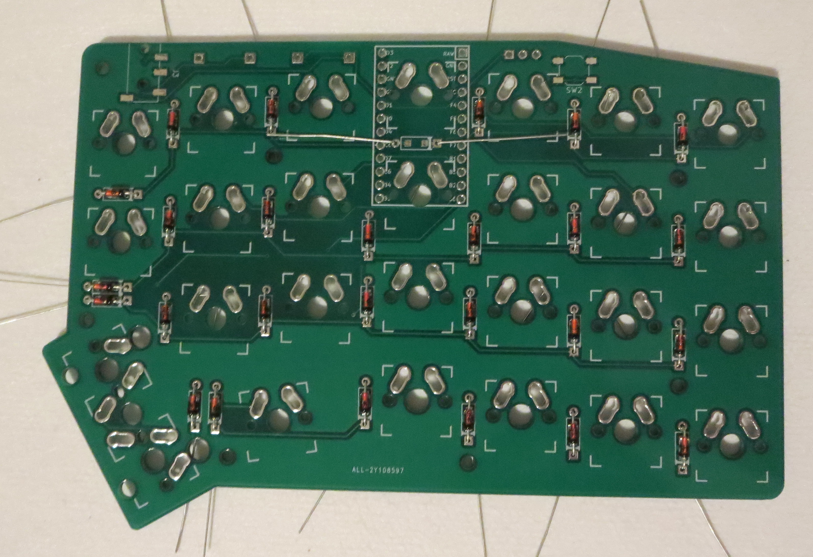
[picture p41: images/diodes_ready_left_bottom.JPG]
diodes left half bottom view


Note the orientation of the diodes that are positioned horizontally.  It is important that the bands on the diodes match the bands on the silkscreen and the square pads.

Diodes ready to be installed on the right half.

Top view:

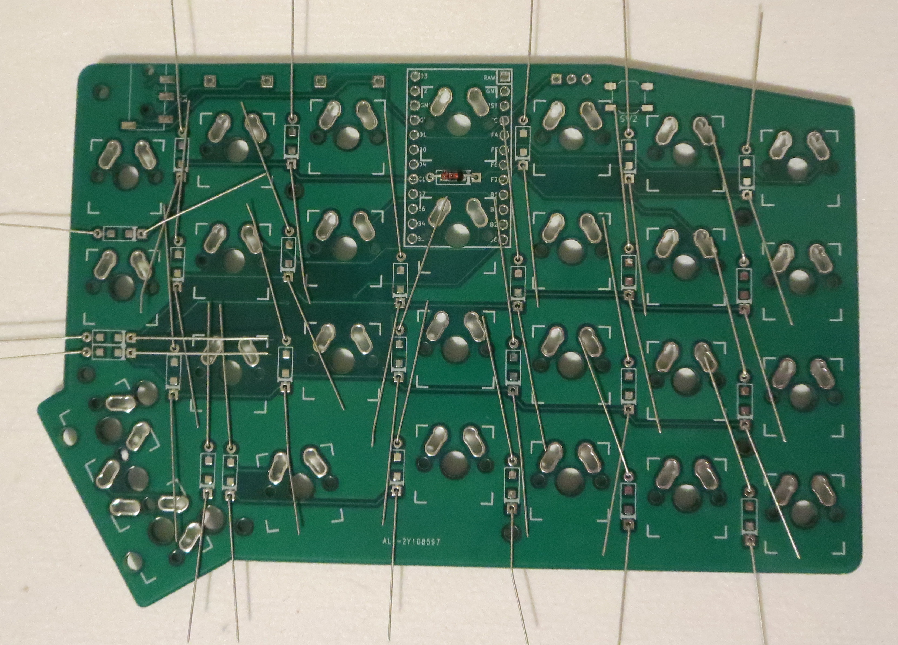
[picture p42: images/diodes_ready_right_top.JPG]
diodes right half top view


The diode beneath the pro micro will need to be placed on top of the PCB so that it does not come in contact with the pro micro.

Bottom view:

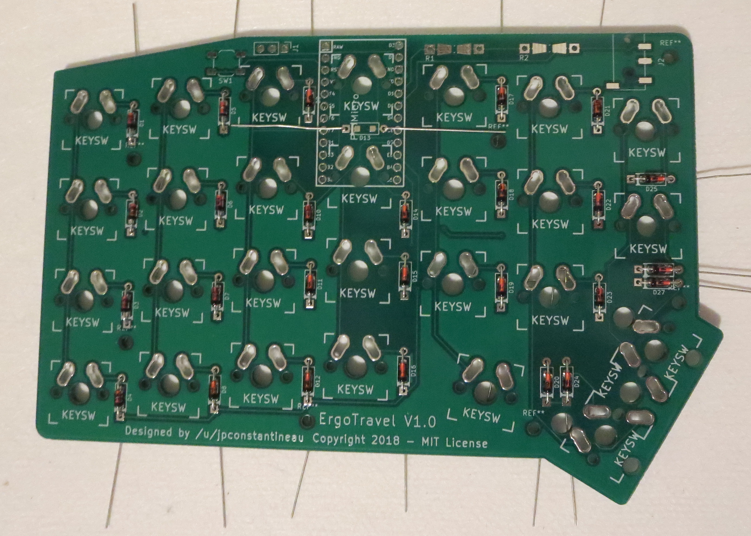
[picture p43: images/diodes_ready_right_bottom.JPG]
diodes right half bottom view


Note the orientation of the diodes that are positioned horizontally.  It is important that the bands on the diodes match the bands on the silkscreen and the square pads.

Once all of the diodes are in place they are ready to be soldered. After soldering, clip the legs on the diodes flush with the PCB.  Do not discard the legs from the diodes if you plan to install sockets for the pro micro.

Diodes soldered on the left half.

Top view:

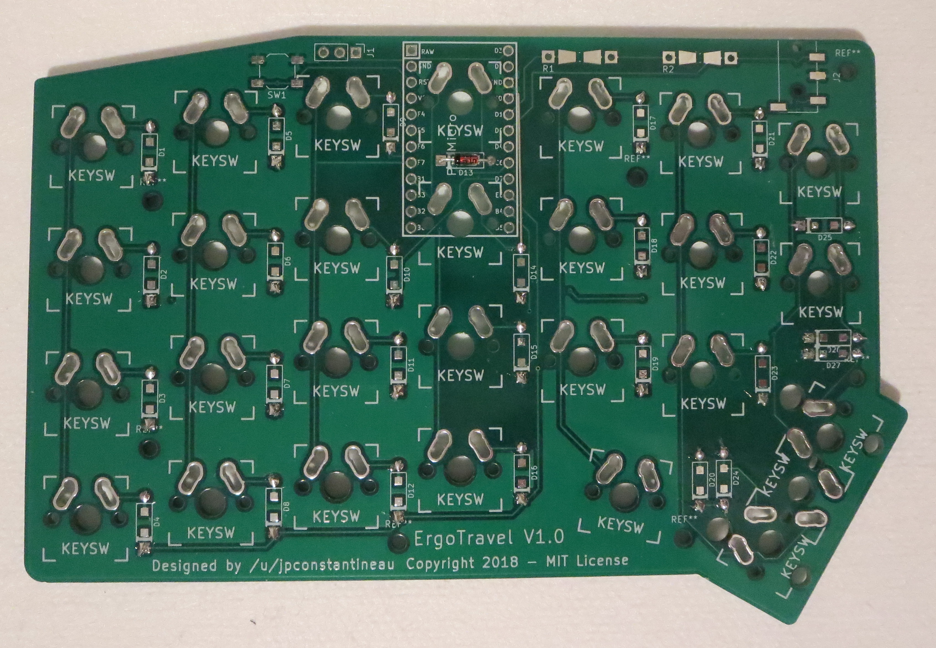
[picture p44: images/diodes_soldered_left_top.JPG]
diodes left half top view


Bottom view:

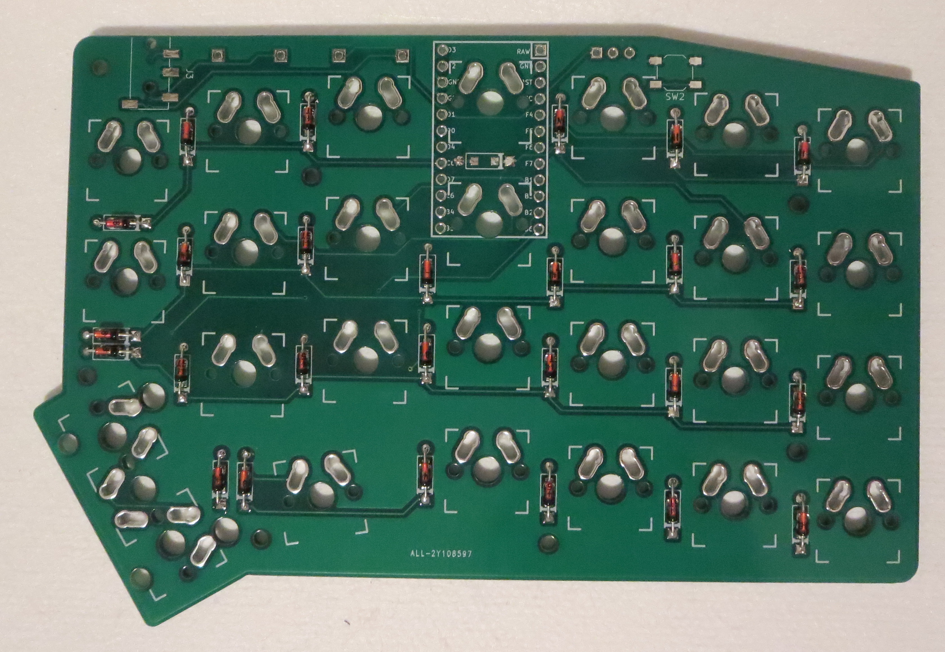
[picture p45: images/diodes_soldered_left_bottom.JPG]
diodes left half bottom view


Diodes soldered on the right half.

Top view:

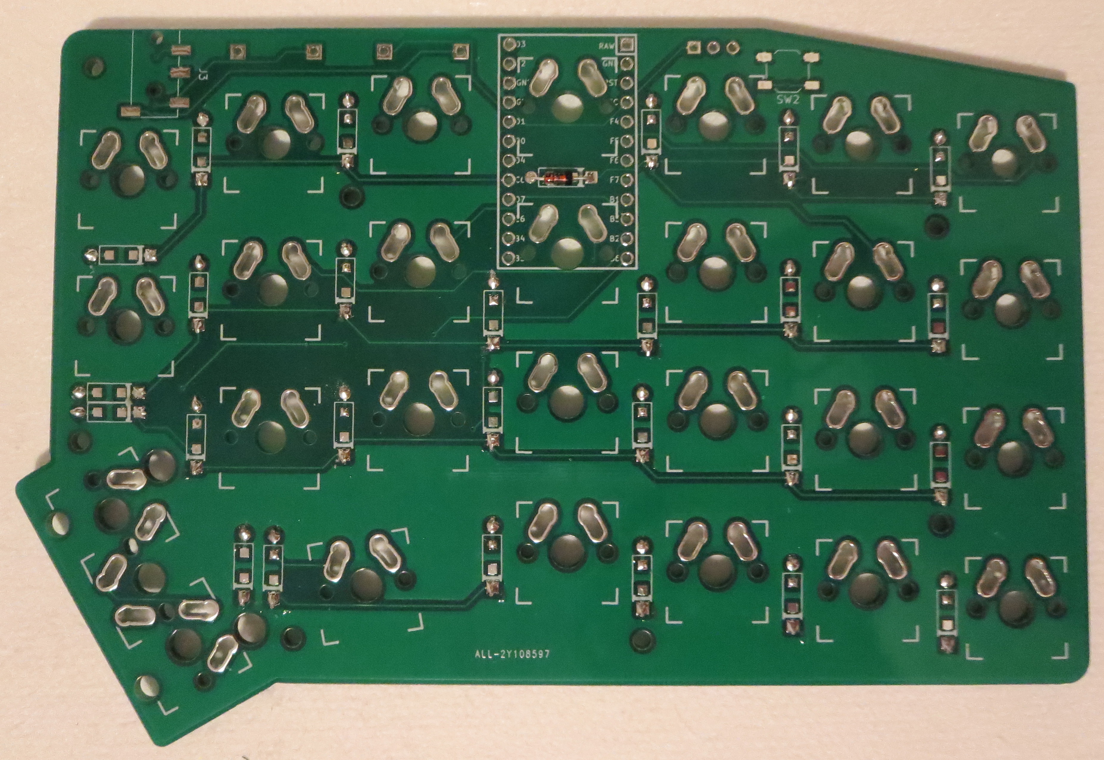
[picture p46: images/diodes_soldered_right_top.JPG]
diodes right half top view


Bottom view:

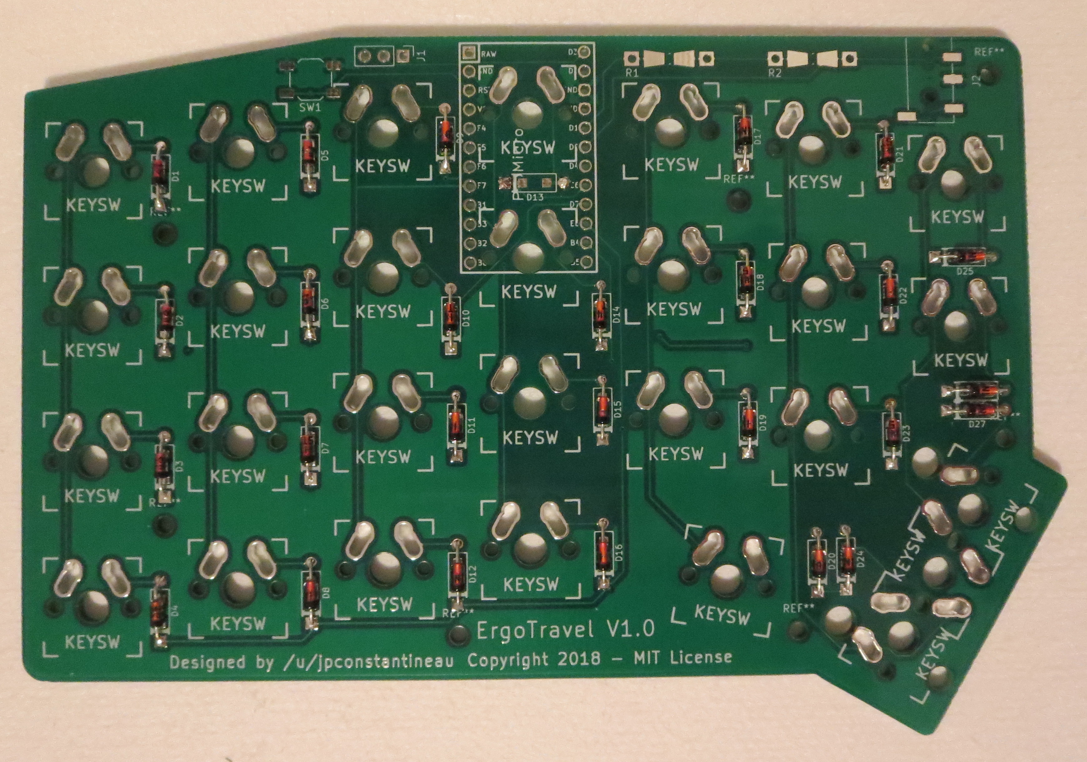
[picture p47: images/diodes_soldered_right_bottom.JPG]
diodes right half bottom view


#### Surface Mount Diodes

The ErgoTravel PCBs are also compatible with surface mount diodes. When placing the diodes, be sure to orient the white lines on the diodes with the bands on the PCB.

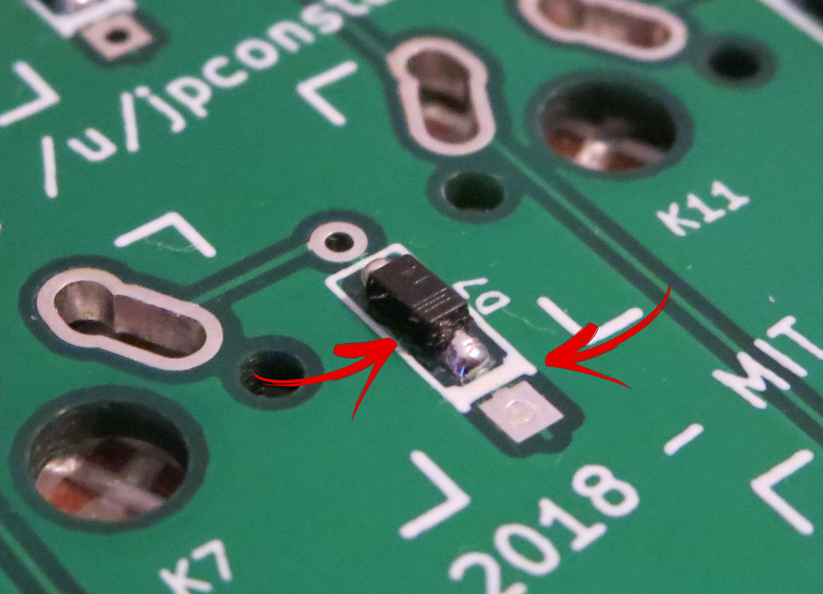
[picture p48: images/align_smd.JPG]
aligning surface mount diodes


Add a small amount of solder to one of the SMD pads.

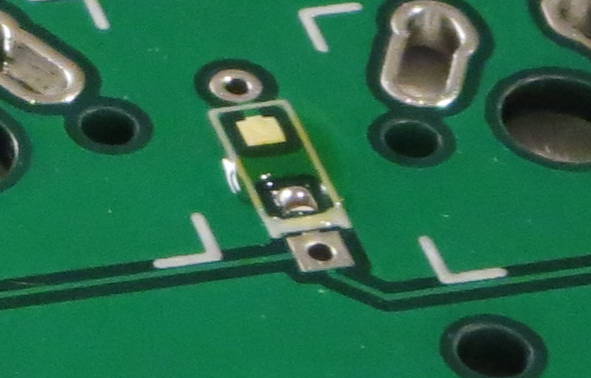
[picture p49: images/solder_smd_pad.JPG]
add solder to smd pad


While holding the diode with tweezers, reflow the solder on the pad and place the diode into position making sure that the bands on the diode align with the bands on the PCB.

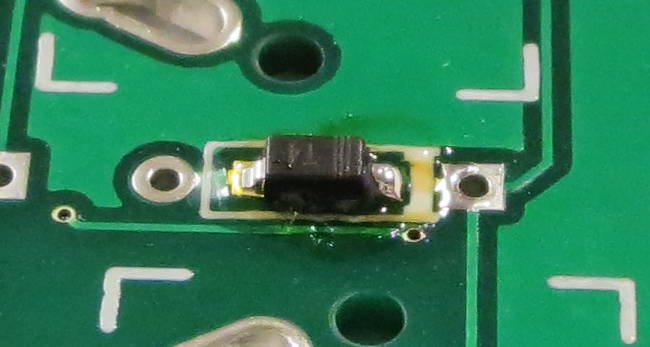
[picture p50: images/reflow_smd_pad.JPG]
solder one side of the diode


With the diode in place, add solder to the other side of the diode.

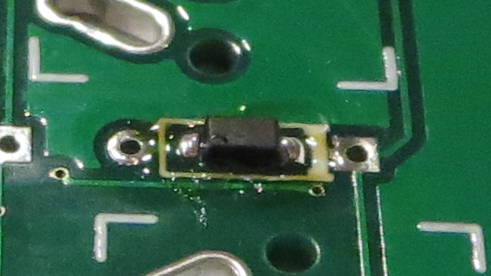
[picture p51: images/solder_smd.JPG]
solder the other side of the diode


Diodes soldered on left half:

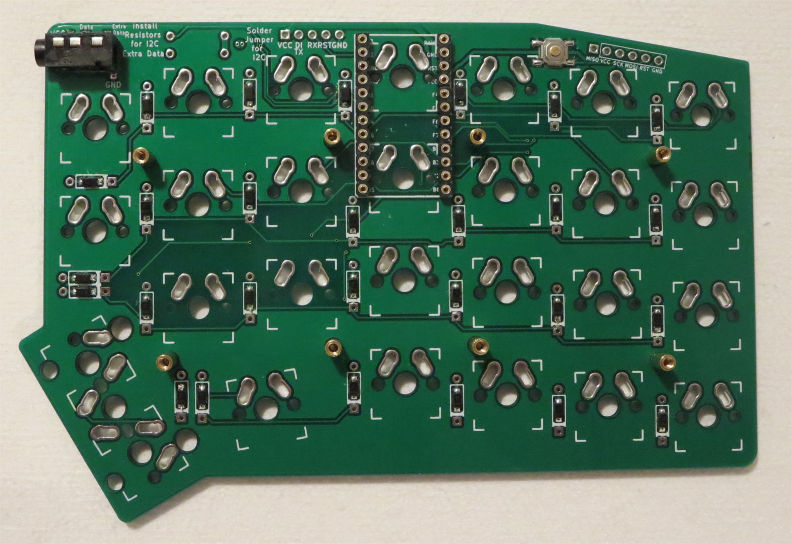
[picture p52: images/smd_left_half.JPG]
cmd components soldered on left half


Diodes soldered on right half:

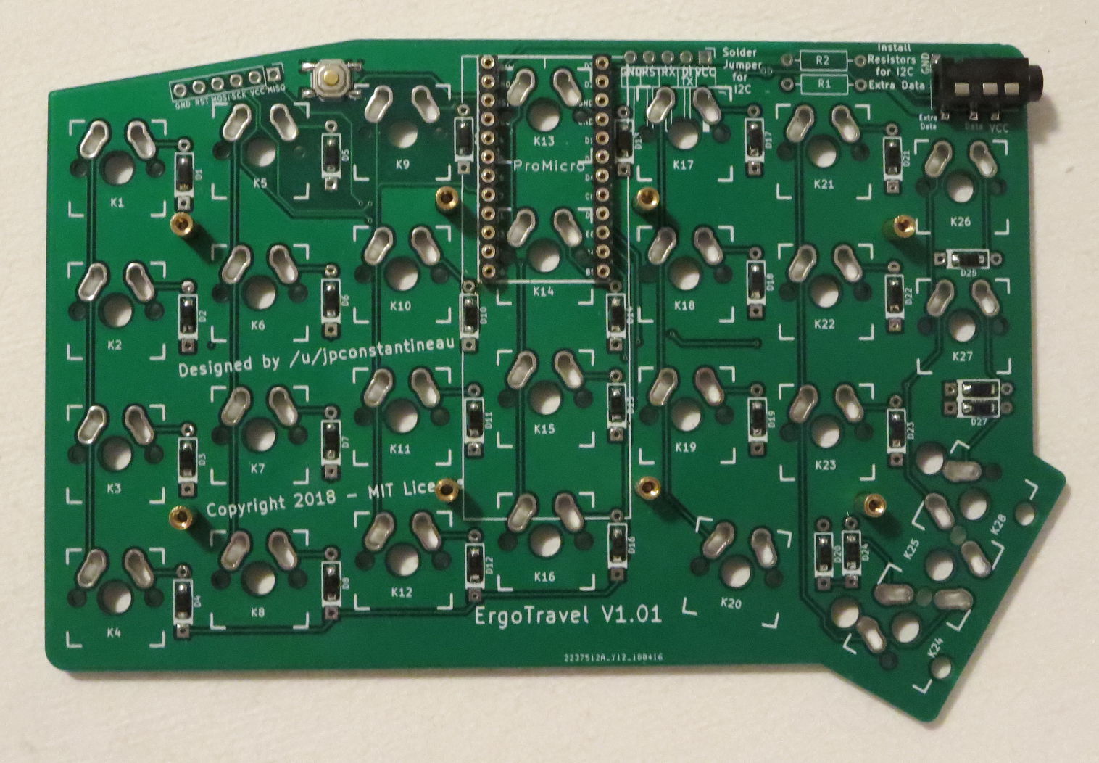
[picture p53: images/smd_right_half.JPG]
cmd components soldered on right half


### Step 4: (Optional for I2C) Install the resistors
**Note that I2C is currently not compatible with WS2812 RGB underglow**
If you are working on the Master Half, install the resistors near the top, on the top side.
You will need to make a solder bridge at the Jumper location on both halves to enable I2C communication. This jumper is located next to the resistors.  Bridge on the "bottom" side so that you have access to it once fully assembled.

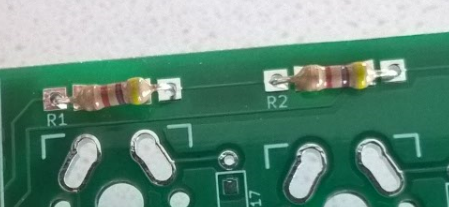
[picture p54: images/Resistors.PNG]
resistors


If you are working on the slave side, continue to the next step. The slave side does not have resistors.  
If resistors are on installed the slave instead of the master, it should still work fine.

### Step 5: Install Reset Switch

Install Reset switch on the **bottom side** of the boards. This is a surface mount switch.

Apply some solder to one of the 4 pads. 

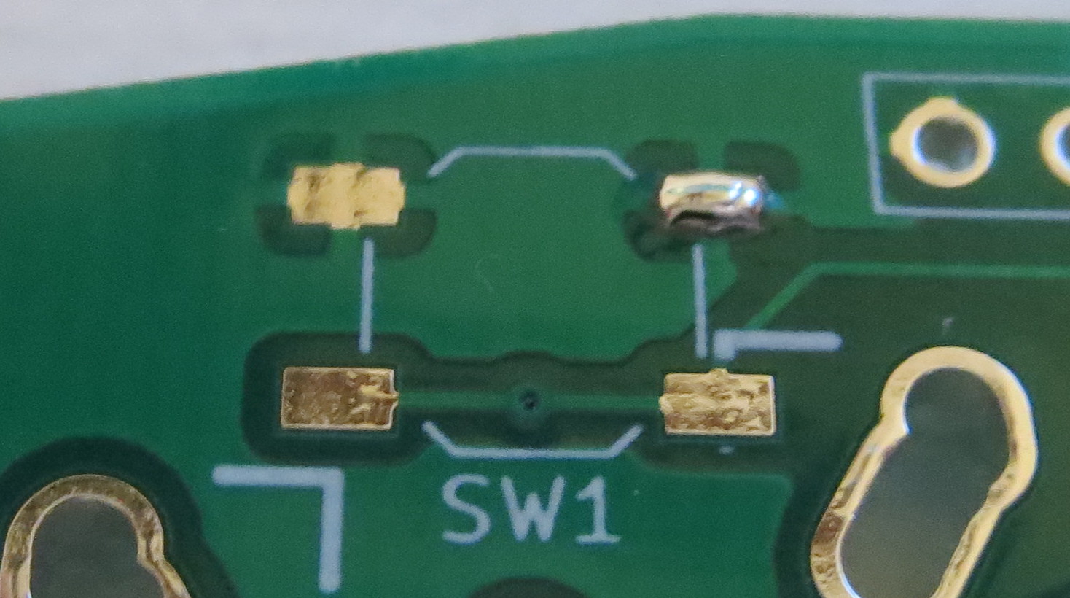
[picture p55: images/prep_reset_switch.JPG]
prep reset switch


Place the switch in position.  Melt the pre-applied solder to "tack" the switch in place. Some recommend to put some solder on the 4 pads.  I find it easier to align the switch if only 1 pad has solder pre-applied. Using tweezers, you can hold the switch and gently touch the leg with the soldering iron and melt the solder. 

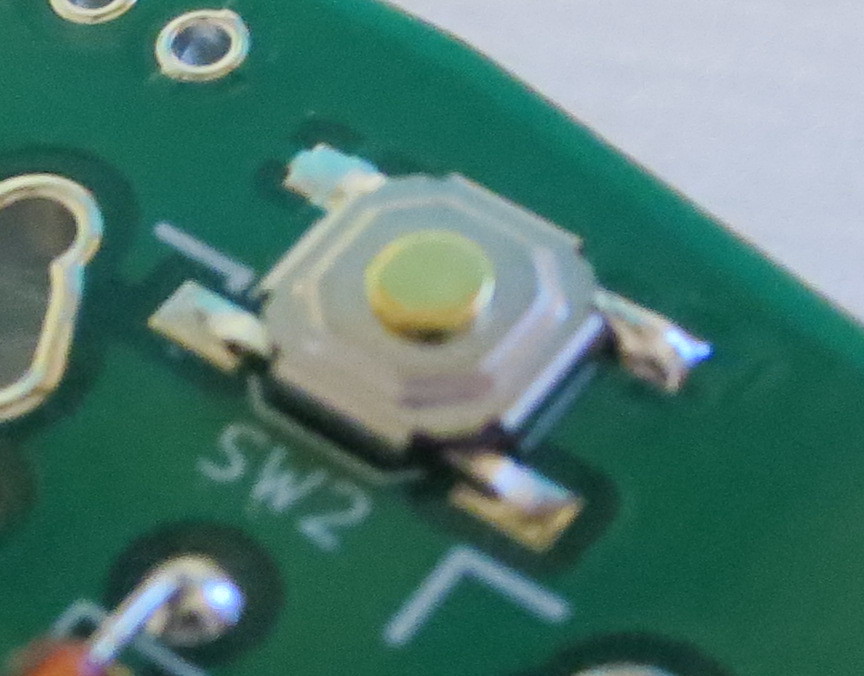
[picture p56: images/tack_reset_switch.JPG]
tack reset switch


Let the solder solidify and solder the other legs.

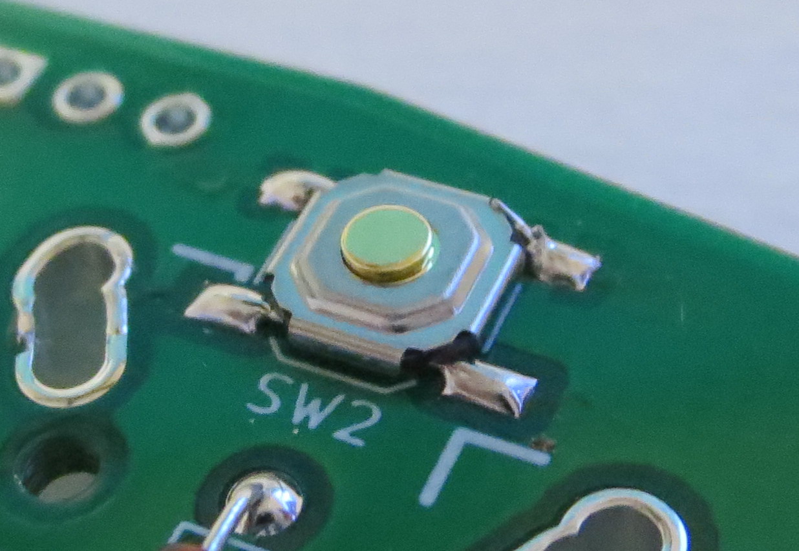
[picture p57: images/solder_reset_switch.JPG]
solder reset switch


### Step 6: Install TRRS Connector

Install TRRS Connector on the **bottom side** of the boards. This is a surface mount connector.  Apply some solder to one of the 4 pads; preferably to the side that had a single connection.

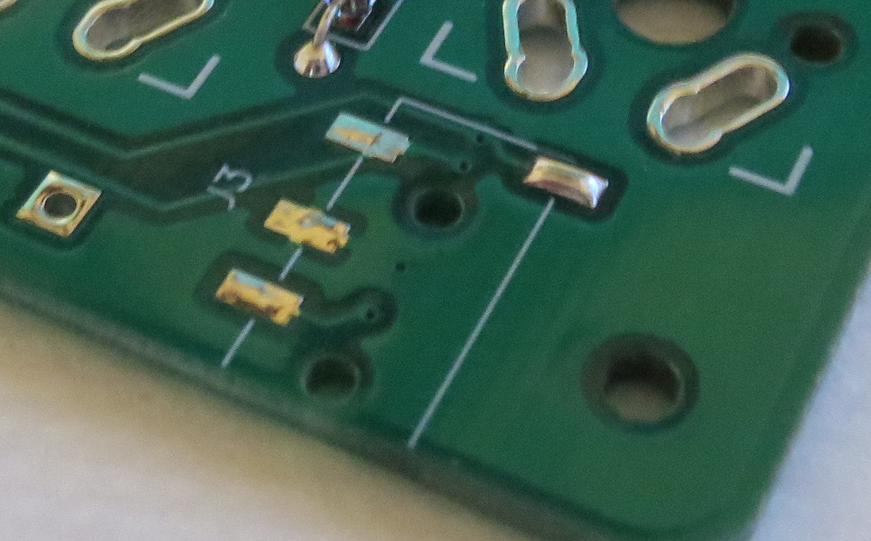
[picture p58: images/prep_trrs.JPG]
prep trrs connector


Place the connector in position.  Melt the pre-applied solder to "tack" the connector in place. Some recommend to put some solder on the 4 pads.  I find it easier to align the connector if only 1 pad has solder pre-applied. Using tweezers, you can hold it and gently touch the leg with the soldering iron and melt the solder.

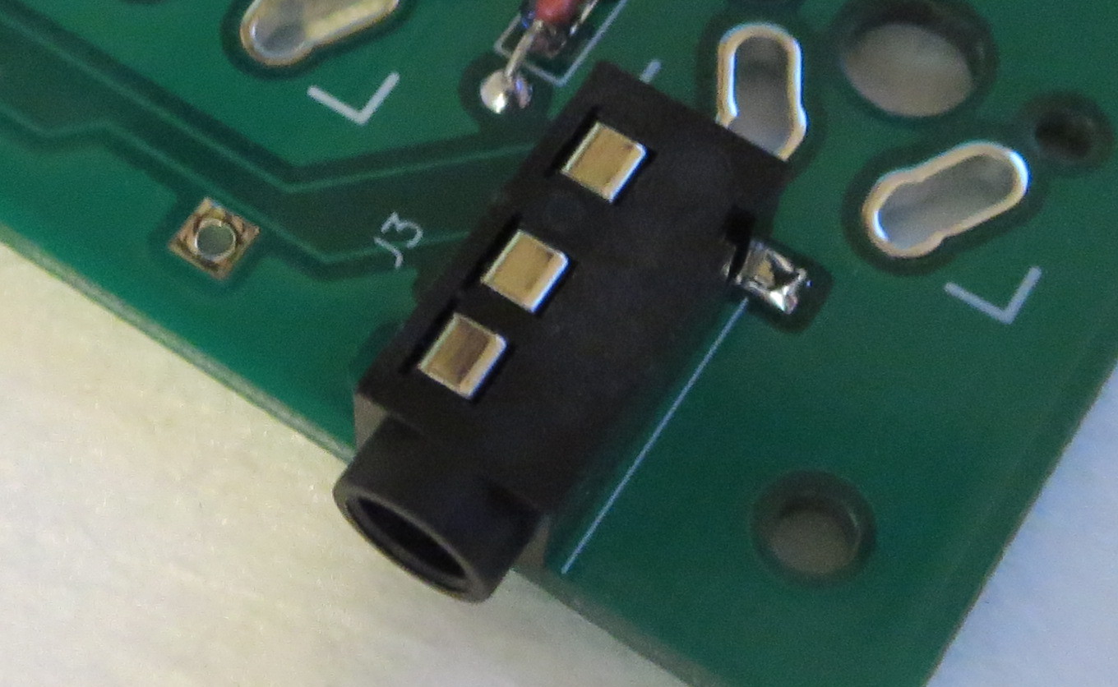
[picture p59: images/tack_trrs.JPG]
tack trrs connector

 
Solder the other 3 connections.

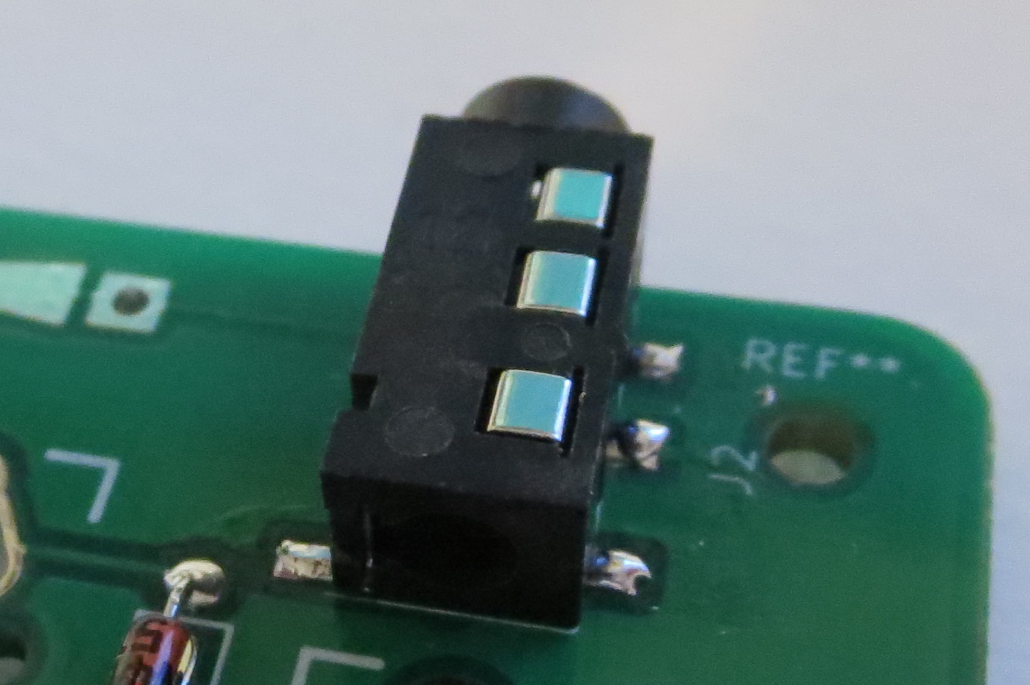
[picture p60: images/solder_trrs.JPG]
solder trrs
  

To increase the strength of the TRRS connectors soldered on top of the board, add a drop of cyanoacrylate glue to each hole from the other side of the PCB.  By using a liquid glue (not a gel),the glue will seep through the hole and insert itself between the PCB and connector.  Let the glue set as per the manufacturer instructions.

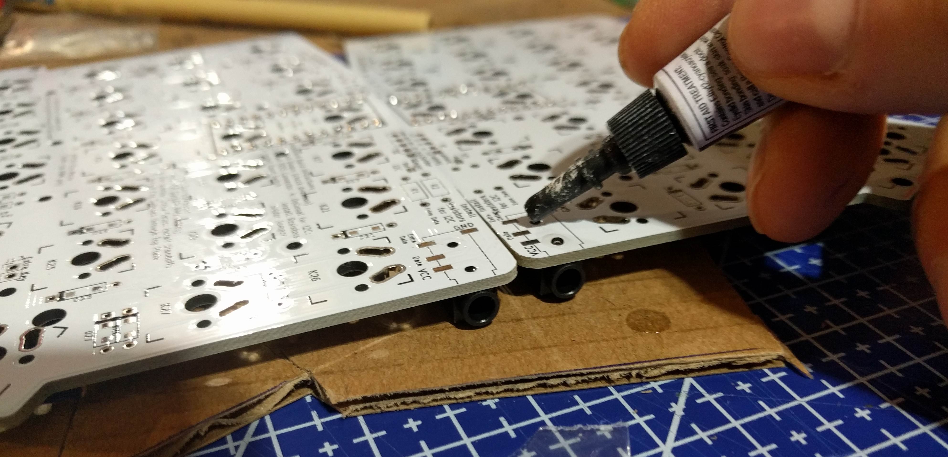
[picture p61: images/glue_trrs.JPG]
glue trrs
  

### Step 7: Option 1 (recommended) Install Pro Micro Sockets 
Install Pro Micro Sockets on the bottom side of the boards. DO NOT SOLDER THE PRO MICRO.

Place the sockets on the boards and use some tape to hold them in place.  

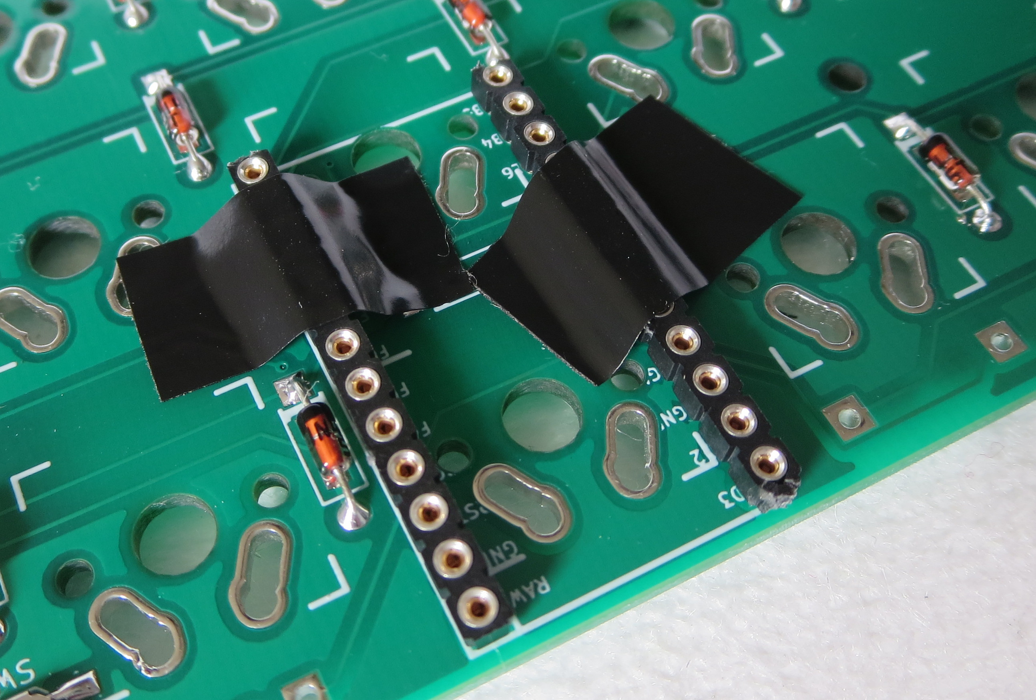
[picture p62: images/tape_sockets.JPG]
tape sockets in place


Once in place, solder a single pin and then remove the tape.  While holding the PCB, press down on the socket with your finger and reflow the soldered pin with the iron.  Properly align the socket, remove the iron, and allow the socket to solidify.  Do not place your finger over the pin that is soldered.  It gets hot.

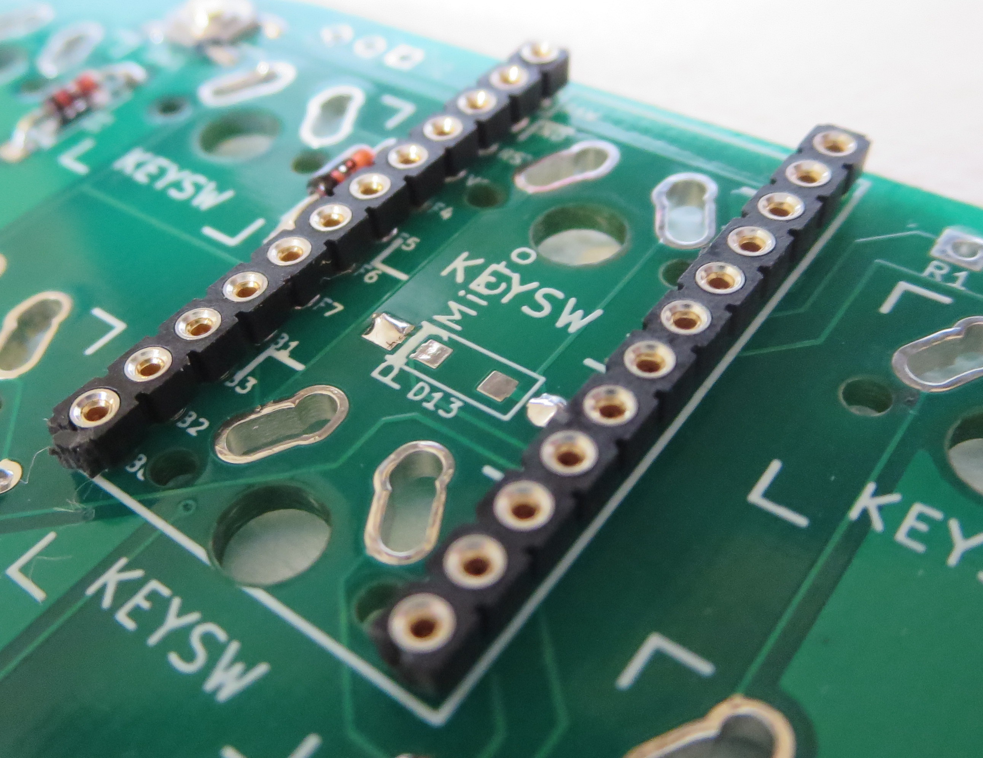
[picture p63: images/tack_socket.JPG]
tack socket in place


After you are satisfied with the alignment of the sockets, solder the pin on the opposite side of each socket to hold it in place. Solder the remaining pins.

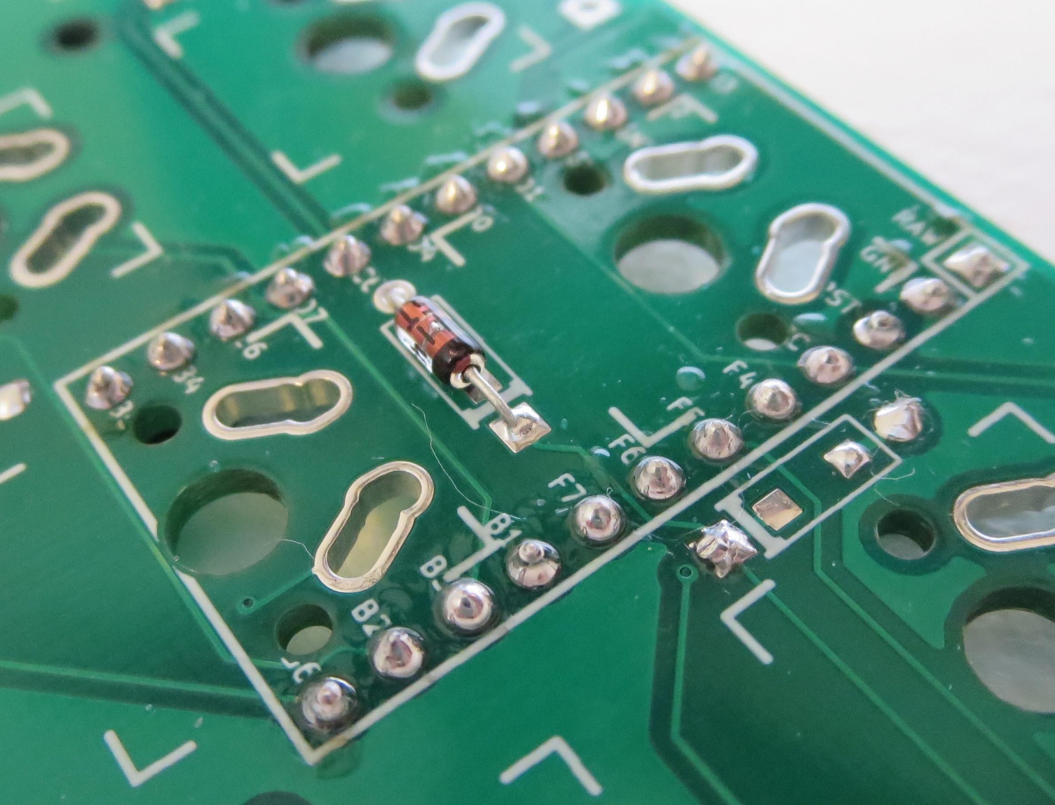
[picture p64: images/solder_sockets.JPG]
solder sockets


### Step 7: Option 2 (not recommended) Install Pro Micro Headers
Install Pro Micro Headers on the bottom side of the boards. DO NOT SOLDER THE PRO MICRO.

PLACE IMAGE HERE

### Step 8: Validate your soldering job and test the diodes...
Validate that the diodes were installed correctly.  Once the switches are installed through the top plate, it will be close to impossible to replace the diodes without unsoldering everything. If the diodes are installed on the bottom of the PCB, it is possible to unsolder the diodes, however, resoldering a new diode will require trimming the leg before soldering. 

### Step 9: Return to Step 3 and continue with the other half.
Only the first half is done...  Rinse and repeat...

Bottom view of the left PCB with all components installed:

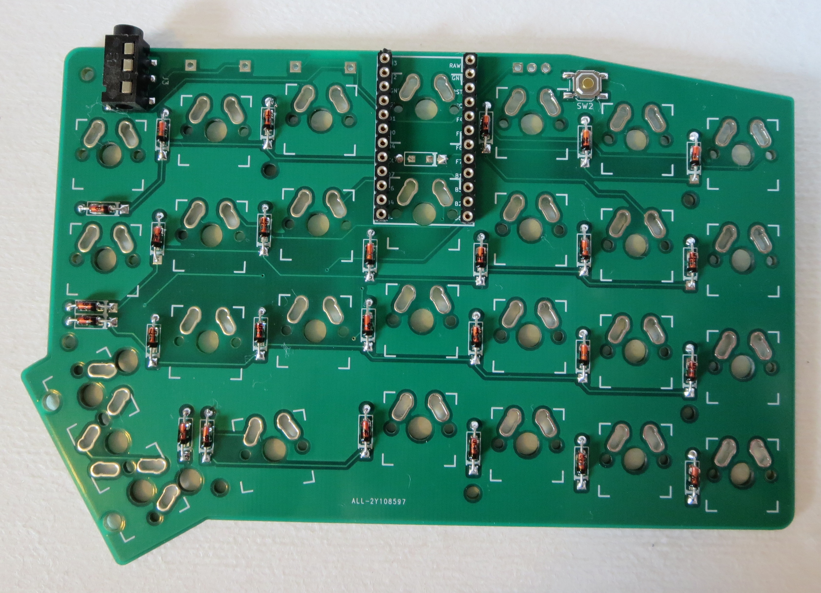
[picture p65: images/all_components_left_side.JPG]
all components left side


Bottom view of the right PCB with all components installed:

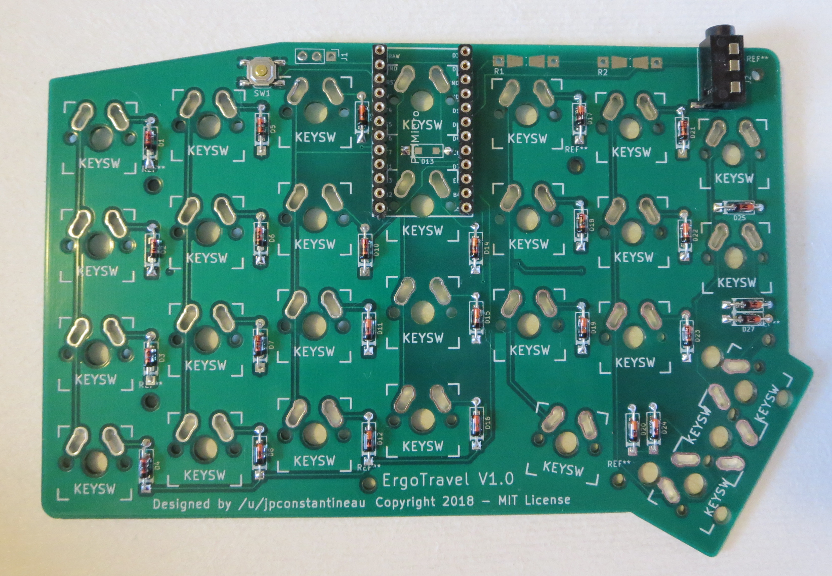
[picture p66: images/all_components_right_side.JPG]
all components right side


---

## Prepare underglow

If you plan on adding RGB underglow, start soldering the connectors now. See [Installing RGB Strips](InstallingRGBStrips.md) for details.

## Decide on Layout and Install Stabilizers

### Step 1: Decide on your layout.
Depending on whether you want 4x1U, 2x1U+1x2U or 1x2U+2x1U or 2x2U, you will require 0, 1 or 2 2U PCB Mount stabilizers. 

### Step 2: Prepare Stabilizers
Depending on where you obtained your stabilizers, you may have to put them together before installing them.
When assembled, they look like this:

stabilizer

### Step 3: Install Stabilizer in PCB
If you want to lubricate your stabilizer or do anything special to them, now is the time...

When installing the stabilizers, the twin legs as shown here:

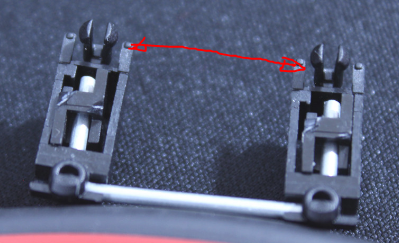
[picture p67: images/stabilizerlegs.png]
stabilizer


are installed towards the "outside" of the PCB.  Note that the hole diameters for installing the stabilizers are not the same between the two sides.  The stabilizer should only fit one way.

stabilizer

To install the Stabilizer, first pass the small single hooks (on the wire side) through the larger holes (towards the center of the board).  

stabilizer

Then press down on the other side of the stabilizers (outside edge of the PCB) to engage the clips within the smaller holes.  You may have to squeeze gently on the twin legs for them to go through the hole.  Once through, the stabilizer will "snap" in place.
 
stabilizer 

The legs should be fully snapped in place for the stabilizer to work properly.

stabilizer 

---

## Install Standoffs for "Internal Screws PCB Case" 
**This step only applies if you have an Internal Screw PCB Top Plate**

_Ignore if you use the "External Screws PCB Case"._

How do you know if you have an External Screws Case or an Internal Screws Case?

See the picture below:
cases 

Installing the screws is not possible from above the top plate.  
The hole on the top plate is large enough to pass a screwdriver through but not enough for the screw head.

cases 

cases 

Take each assembled PCB and install the screws and standoffs right now. See the two pictures below:

cases
cases

Once assembled, the screws will be hidden from the top.  Seen from the side, the standoffs only go between the PCB and Bottom plate.
The Top Plate is only held by the friction with the switches.  This is similar to the GH60 and the Contra.

cases

---

## Install Switches

Select the top plate for the side you are building.  Inspect carefully both sides of the plate for imperfections (put them inside to hid them) or, in the case of the acrylic plates, for which side is engraved for the stabilizer wire.  

Place the Top plate above the PCB and install switches at each corner to hold everything in place.  Solder the four switches in while pressing down on the PCB to push the PCB and switches together.

solder corner switches

Once the corner switches are installed, install the remaining switches and solder them in place.

solder all switches in place

---
## Test and Flash Pro Micros

It's easier to replace a faulty Pro Micro if it's not already installed.

---
## Install Pro Micro

Pro Micro Orientation - it is important to orient the controllers in the correct direction.  The Pro Micro on the left side of the keyboard will have the components facing toward the bottom plate. The Pro Micro on the right side of the keyboard will have the components facing the PCB. NOTE: The PCB has an indication of the **RAW** pin.  Match this pin with the silscreen of the Pro Micro.

pro micro orientation

In the photo above, the left side of the keyboard is on top and the right side of the keyboard is on the bottom.

### Steps for completing Pro Micro installation using sockets

Tape over the sockets using painter's tape so that the Pro Micro does not get soldered directly to the sockets. Press firmly on the tape in order to see the outline of the sockets.

tape over sockets

Use the diode legs that were saved from the previous steps.  Insert a couple of the pins in order to line everything up and then place the Pro Micros on top of the sockets. Make sure to face one up and the other down.  **Do not face the Pro Micros in the same direction** Insert pins into the remaining holes.

pin pro micro facing up

pin pro micro facing down

Once the pins are in place, solder the Pro Micros. After soldering, use flush cutters to trim the excess wire. Use a small flathead screwdriver to pry the Pro Micros out of the sockets in order to remove the tape.

pro micros removed from pcbs

### (Optional) Use hot glue to reinforce USB micro connectors

After gluing around the edges of the USB connectors, us a sharp hobby knife to cut off any excess glue.

hot glue

## Having Problems once it is all built?

Go to the [troubleshooting guide](/Troubleshooting_steps.md)

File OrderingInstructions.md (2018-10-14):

ErgoTravel
====

Unless you get your ergotravel from a group buy, you will need to order all the parts for your Ergotravel yourself from various suppliers.  All the design files are available on this GitHub repo.  for the Gerber Files, see this [folder.](https://github.com/jpconstantineau/ErgoTravel/tree/master/GerberFiles/V1.03_Final)

## Parts to order

For a Plate Mount:

| QTY |  Description |  Supplier |
| :---: | :--- | :---: |
| 2  |  PCBs		|							 [AllPCB](https://www.allpcb.com/online_quote.html?hidLength=&hidWidth=&num=&txtSelNum=&Layersquote=2&Thicknessquote=1.6), [JLCPCB](https://jlcpcb.com/quote), [EasyEDA](https://easyeda.com/order)  |
| 2  |  Top Plates |							 [AllPCB](https://www.allpcb.com/online_quote.html?hidLength=&hidWidth=&num=&txtSelNum=&Layersquote=2&Thicknessquote=1.6), [JLCPCB](https://jlcpcb.com/quote), [EasyEDA](https://easyeda.com/order)  |
| 2  |  Bottom Plates |							 [AllPCB](https://www.allpcb.com/online_quote.html?hidLength=&hidWidth=&num=&txtSelNum=&Layersquote=2&Thicknessquote=1.6), [JLCPCB](https://jlcpcb.com/quote), [EasyEDA](https://easyeda.com/order)  |

For a PCB Mount:

| QTY |  Description |  Supplier |
| :---: | :--- | :---: |
| 4  |  PCBs		|							 [AllPCB](https://www.allpcb.com/online_quote.html?hidLength=&hidWidth=&num=&txtSelNum=&Layersquote=2&Thicknessquote=1.6), [JLCPCB](https://jlcpcb.com/quote), [EasyEDA](https://easyeda.com/order)  |

How do I order PCBs? Follow the great guide at [40percent.club](http://www.40percent.club/2017/03/ordering-pcb.html)
 
I recommend ordering your PCBs from JLCPCB or EasyEDA.  You will be able to order the following components and combine the shipping with the PCBs (LCSC, JLCPCB and EasyEDA are sister companies):

| QTY |  Description |  LCSC Part No |
| :---: | :--- | :---: |
| 2  |  4.7KO (4701) ±1% | [C58678](https://lcsc.com/product-detail/Metal-Film-Resistor-TH_4-7KR-4701-1_C58678.html) |
| 2  |  PJ-320D-A TRRS Connector |  [C95562](https://lcsc.com/product-detail/Audio-Connectors_PJ-320D-A_C95562.html) |
| 2  |  Switch 5.2*5.2*1.5 250gf Copper head |  [C92584](https://lcsc.com/product-detail/Tactile-Switches_Switch-5-2-5-2-1-5-250gf-Copper-head_C92584.html) |
| 2  |  2.54mm 1*40P round Female header |  [C9811](https://lcsc.com/product-detail/Female-Header_2-54mm-1-40P-round-Female-header_C9811.html) |
| 56 |  1N4148 Switching Diode |  [C14516](https://lcsc.com/product-detail/Switching-Diode_1N4148_C14516.html) |

Note that the lcsc socket above (part C9811) is a tall socket.  If you want an ultra low profile socket which is the same height as headers, look for the MillMax ultra low sockets [digikey](https://www.digikey.ca/product-detail/en/mill-max-manufacturing-corp/315-93-164-41-003000/ED4864-64-ND/279656).  These are expensive but worth it.

| QTY |  Description |  Supplier |
| :---: | :--- | :---: |
| 54 |  Cherry MX or Compatible Mechanical Switch  | Aliexpress |
| 2  |  2u Cherry MX PCB Mounted Stabilizers	|	  Aliexpress |
| 2  |  Pro Micro Clone 5V | Aliexpress |
| 16 |  M2*4 screws (if using PCB Mount or internal screws case) |  Aliexpress |
| 8  |  M2*8 standoffs (if using PCB Mount or internal screws case and headers or ultra low profile sockets) |  Aliexpress |
| 8  |  M2*10 standoffs (if using PCB Mount or internal screws case and tall sockets) |  Aliexpress |
| 18 |  M2*4 screws (if using Plate Mount external screws case) |  Aliexpress |
| 9  |  M2*12 standoffs  (if using Plate Mount external screws case and headers or ultra low profile sockets) |  Aliexpress |
| 9  |  M2*14 standoffs  (if using Plate Mount external screws case and tall sockets) |  Aliexpress |

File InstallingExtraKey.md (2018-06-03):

### Installing an extra Thumb Key

There is an unused position in the matrix.

matrix

As of V1.02, this empty position has been made accessible on the PCB.

pcb

Install D28 and handwire the additional switch to the 2 pin header located near the thumb cluster.

This extra key allows a modification to the keyboard similar to this [one](https://imgur.com/a/Vr0oH#H5ut7ZZ) on the Iris.

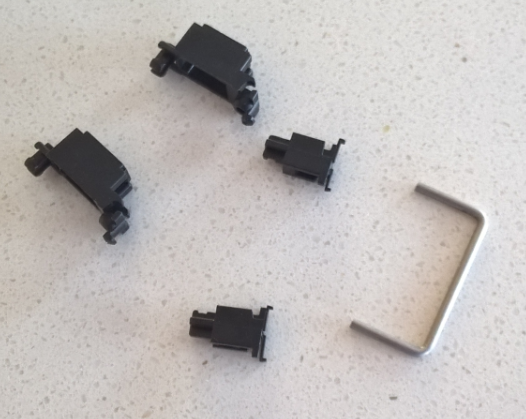
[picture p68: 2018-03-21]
images/Stab_Assembly_1.PNG

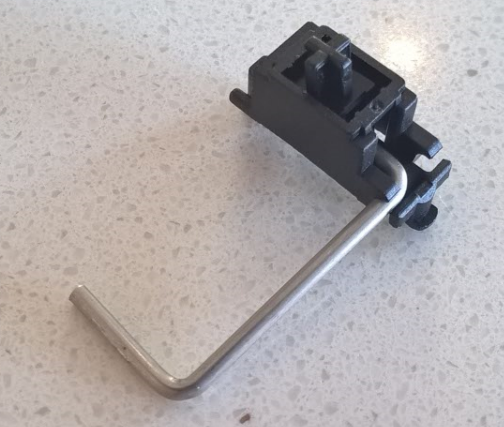
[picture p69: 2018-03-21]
images/Stab_Assembly_3.PNG

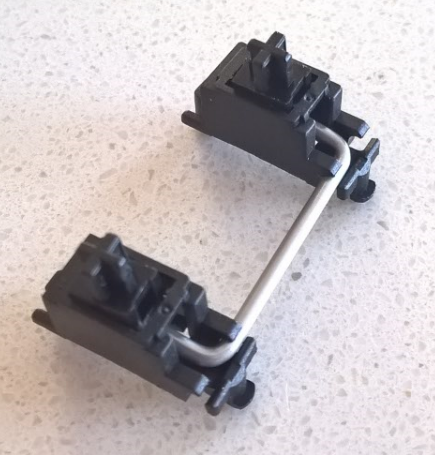
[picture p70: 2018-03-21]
images/Stab_Assembly_4.PNG

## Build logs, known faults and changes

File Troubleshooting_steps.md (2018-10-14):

# Troubleshooting steps

## Troubleshooting tools

* Multimeter with continuity testing and diode testing modes
* [Circuit Diagram](/PCB/ErgoTravel_V1.03_Schematic.pdf)
* [ATMega32U4 Pinout diagram](https://www.arduino.cc/en/Hacking/PinMapping32u4)

## Specific Key is not working

If a specific key is not working but other keys in the same column and row are working, then it's likely the following:

* diode is installed in the reverse orientation
* diode is partially soldered (soldered only one side)
* diode is not functionning properly (unlikely - test with diode testing mode of multimeter)
* switch is not partially soldered (soldered only one side)
* switch is faulty (unlikely)
* PCB traces have been cut

Most often this is due to a diode installed in the reverse direction.  Unsolder the diode and re-install it the other way around.

## A whole Column or a whole Row is not working

If a whole column (or row) is not working, then it's the conection between the column/row and the microcontroller on the pro micro that's problematic.
With a continuity meter, check the following:

* (for columns) continuity between the non-diode side of the switches for that column and the pro micro pin - on the PCB socket.
* (for rows) continuity between the "band-side" of the diodes for that row and the pro micro pin - on the PCB socket.
* continuity between the PCB socket and the pro micro pin.
* continuity between the pro micro pin and the microcontroller pin

Very often when using a socket and diode legs, the issue is that the connection between the socket and the diode leg is faulty.  This is due to a "thin" diode leg that doesn't conctact the socket properly.
Resolving this issue is as simple as slightly bending the diode legs in a "S" shape rather than perfectly shaped "I" (curvy instead of straight).  This will improve the side to side contact between the socket and the diode legs and generally resolve the connection issue.

Very rarely (but it happens), the issue is on the pro micro itself.  The micro controller chip is not soldered properly to the Pro Micro PCB.
You can test this with the third test above.  In such cases, installing a small wire/jumper between the Pro Micro pin and the specific pin of the microcontroller will resolve the issue.  Use the ATMega32U4 pintout diagram to identify which pin is the one to check for continuity.

## Two adjacent keys are being registered when a single one is pressed

This can occur with cheap grab bag kecaps.  The keycaps have some plastic injection points that protrude under the next keycap.  When pressing the key, the small plastic tab is long/big enough to get caught under and force the second key to go down as well.
Remove the keycap and cut the protruding plastic tab and re-install.  

If this occurs when there are no keycaps on the switches, then go to the next section.

## Two adjacent rows or columns are being registered when a single key is pressed.

This is likely due to a short between two colums or two rows.  Check the soldering on the Pro Micro pins and verify that adjacent pins don't have continuity.  If this is the case, remove solder from these pins and re-check for a short.

It's unlikely but not impossible that the short is at the microcontroller itself. Visually check the microcontroller pins for a short between two microcontroller pins.

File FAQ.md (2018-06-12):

 
## Q: Does this support USB-C cables?

**A:** For supporting USB-C, the ErgoTravel uses 2 Pro Micros. 
Until someone makes a Pro Micro with USB-C, all that's going to be available will be micro-USB. 
Going with USB-C would allow for more power hungry features in a keyboard like per-key RGB.

## Q: Could we use USB cables instead of TRRS cables for communication between the two halves?
**A:** For the connection between the two halves, I would steer away from using a USB cable. 
Communication is through I2C and although relying on a USB cable is sound "electrically", the protocol is very different. 
At some point, someone stupid enough would assume that they could connect any of the USB-C from one half to any USB-C of the other half and start complaining that it is not working. 
By using different cables, one removes this possibility. Switching to USB communication between the two halves would be impossible with the current pro micros. 
One would have to change the micro controller and that would make the keyboard much more difficult to develop and support (no QMK perhaps?).

## Q: Does it support bluetooth?
**A:** Yes and No. When each half uses a Pro Micro, the keyboard is based on the ATMEGA32U4 and runs QMK. BlueTooth isn't supported when using the Pro Micro on the ErgoTravel.  When a BlueMicro is installed instead, the keyboard uses the nRF52832 and runs an Arduino firmware based on the Adafruit nRF52 Libraries.  The BlueMicro is a Bluetooth-Only solution.

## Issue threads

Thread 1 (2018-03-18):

VCC Power Lines are too thin

jpconstantineau, 2018-03-18:
VCC passes through the TRRS connector and may power WS2812 RGB LEDs on the other side.  As such resistance of thin VSS lines may affect brightness of LEDs.

jpconstantineau, 2018-03-21:
Fixed.

Closed 2018-03-21.

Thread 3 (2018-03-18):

Switch Labels are not numbered

jpconstantineau, 2018-03-18:
Instead of having generic large switch labels on the silkscreen, we can number them to match the diode IDs

jpconstantineau, 2018-03-21:
Removed Value Visibility and added visibility to references

Closed 2018-03-21.

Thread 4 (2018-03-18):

Standoff screw holes are labelled but should not

jpconstantineau, 2018-03-18:
There are generic labels that are present on the silkscreen.  These are not necessary.

jpconstantineau, 2018-03-21:
Removed reference visibility

Closed 2018-03-21.

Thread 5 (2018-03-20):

Top Plate: Add Location where PCB Fab shops can write their Job ID

jpconstantineau, 2018-03-20:
Check with EasyEDA and other fabs to see what label to put for them to replace for the job ID.

Job ID should be between switches so that it does not show up when KB is fully assembled.

jpconstantineau, 2018-03-21:
For JLCPCB, Add "JLCJLCJLCJLC" to a location where it's hidden. Not sure about which layer. See [here](https://support.jlcpcb.com/article/28-how-to-remove-the-customer-id-on-the-pcb) for details.

For other fab shops, not sure.

jpconstantineau, 2018-03-27:
Provided locations for Internal PCB case plates. (Top/Bottom)

jpconstantineau, 2018-07-26:
Completed

Closed 2018-07-26.

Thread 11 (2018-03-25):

Complete ordering guide

jpconstantineau, 2018-03-25:

dbordak, 2018-06-21:
I'm interested in buying an ergotravel, but the current ordering instructions are a bit insufficient for me. If you could help me through that, I could document the process and PR it. I know it'd probably be just as much effort on your part, but I find talking easier than writing, personally :)

jpconstantineau, 2018-06-21:
I understand that the ordering instructions are a bit scarce right now. I have a Group Buy running right now.  If you are willing to wait and join in, you will be able to get it at a better price than ordering small quantities from the PCB fabs.  Once the GB is complete, I will have a complete list of parts and where to obtain them.

Also, I am making small changes to the gerber files as I am still getting some input from the beta testers.

I do have some beta tester boards available if you are really in a rush to get things and want to contribute to testing the board and building process. See [here](https://www.reddit.com/r/mechmarket/comments/8ssgu4/gb_ergotravel_group_buy_update_2/) for the GB details.

If you do want to contribute to the instructions and make the necessary changes, you can start from the instructions [here](http://www.40percent.club/2017/03/ordering-pcb.html).  They are not completely up to date but very close.

dbordak, 2018-06-22:
I actually already signed up for the GB, but I'm also kinda hype for it and want one now :P
It fits all my needs (or at least, what I think I've determined I want) for a keyboard without anything extra -- and I've found that forcing myself to use chording rather than reaching for an extra row/column feels better.

jpconstantineau, 2018-10-14:
I have updated the ordering guide; however, I am leaving is as a BOM with a few links. Closing the issue

Closed 2018-10-14.

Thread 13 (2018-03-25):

Is top plate good with plate mount switches

jpconstantineau, 2018-03-25:

viet-pham, 2018-03-30:
cherry mx blacks snapped into place really well on the switch plate.  took some force to pop the switch back out after testing.

jpconstantineau, 2018-04-12:
Top Plate Good. Thanks

Closed 2018-04-12.

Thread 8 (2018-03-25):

What type/brand socket allow for 12mm standoffs

jpconstantineau, 2018-03-25:

viet-pham, 2018-04-04:
the digikey ultra low profile sockets leave ~2mm between the usb connector and bottom plate.  if you use the headers that come with the pro micro and pry off the black plastic, the pro micro can be soldered much closer to the pcb potentially allowing for <=9mm sockets.

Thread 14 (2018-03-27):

Holes for PCB mounted switches are too tight

ckofy, 2018-03-27:
I’ve tried to insert the Zealios switch to the PCB and it is very hard going. I’ve measured the diameter of the switch’s pins as 1.7 mm.

jpconstantineau, 2018-03-27:
Cherry Specs indicate putting holes at 1.7mm diameter.  Keebio uses 1.8mm holes for his footprints.

ckofy, 2018-03-27:
I've found what causing that issue. Pins of Zealios switches have a little excess of of plastic on the inner sides making them not perfectly round. Grinding that excess out with a little file makes the switch to fit nice in the ErgoTravel PCB, but after that procedure it starts to fall out of the Iris PCB.

jpconstantineau, 2018-03-27:
Production Tolerances on drill sizes could also be a factor:
From JLCPCB Capabilities page:
Hole Size Tolerance | ±0.08mm | e.g. For the 0.6mm hole, the finished hole size between 0.52mm to 0.68mm is acceptable.

jpconstantineau, 2018-11-15:
I won't be making the changes to the footprint.

Closed 2018-11-15.

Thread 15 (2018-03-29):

Move diode D13 outside of the area where the pro micro will be installed

viet-pham, 2018-03-29:
moving the diode will ease diode install and would allow for all diodes to be installed underneath the PCB

jpconstantineau, 2018-03-30:
Moved to other side of header/socket.

Closed 2018-03-30.

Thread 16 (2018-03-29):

Holes for diodes could be slightly larger

viet-pham, 2018-03-29:
the smaller holes makes it easer to keep diodes in place when soldering, but you have to bend the legs exactly right.

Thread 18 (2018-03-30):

Label TRRS connector Signals

jpconstantineau, 2018-03-30:
This will help everyone in troubleshooting connection issues.

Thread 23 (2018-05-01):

V1.01 Silkscreen extra lines

jpconstantineau, 2018-05-01:
Silkscreen has a few extra lines around the serial header.

jpconstantineau, 2018-05-11:
Connector was "angled" instead of straight.  Silkscreen has an image of the pins.  Fixed.

Closed 2018-05-11.

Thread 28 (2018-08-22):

Serial implementation

Derecho, 2018-08-22:
I was looking at your code as a friend is making their own ErgoTravel keyboard, and something's puzzling me a little.

So as far as I understand, to link the two halves of the keyboard, either I2C or "regular" serial is used (with a TRRS cable). I see the defines in the code to choose between the two protocols, but the files for serial seem to be missing in this repository? I did find them in this merge commit: https://github.com/qmk/qmk_firmware/pull/3129/files

Now I might be misinterpreting things, but from the serial.c and serial.h I can see there, it looks like software serial is used (bitbanging) on port PD0. Why? I'd assume hardware serial (on PD2/PD3) would be preferred, since that makes timing a lot easier and it saves you some instructions. I wouldn't be surprised if you could push that to greater speeds too, thus reducing latency (on the slave half).

One reason I can think of, but this is just speculation, is that I2C was implemented first (of which the pins are on PD0/PD1) and serial support was added later, and that one wanted to keep pin compatibility between the two. Is this it, is there another reason, or did I completely misinterpret the serial operation?

jpconstantineau, 2018-08-22:
The implementation is derived from the Iris and ultimately the original split board: the let's split.  The Let's Split uses serial big-banging or I2C on the same lines.  In order for everything to be consistent with everyone's design, I kept the same lines.

I don't know if tx/rx was ever tried/used between two halves. I agree with you that it would make sense.  However, many implementations use bi-directional serial over a single line so that the extra wire of the TRRS line is used for the data line of the RGB underflow strips.  I suspect that this is the primary reason why a single line is used.

There has been a few attempts to get RGB to work over I2C but I am not aware of any that have been completely successful. (Getting the RGB patterns to sync between the halves isn't trivial. With the extra line connecting DO to DI of the master/slave strips, one doesn't have to worry about syncing the two sides)

SethBarberee, 2018-08-30:
Actually, the [Let's Split Eh?](https://github.com/qmk/qmk_firmware/tree/master/keyboards/lets_split_eh) is purely I2C and has support for RGB. The support of the Let's Split Eh? of RGB started the split common library of QMK mentioned in #27. Currently, only static RGB is supported. Animations haven't been implemented yet by Canadian (the main guy behind Let's Split Eh?).

Closed 2021-11-24.

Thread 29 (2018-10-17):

PCB Choc tested?

Cwejman, 2018-10-17:
Hi,

I'm eager to order and assemble my first split keyboard. I've ended up here after trying to make up my mind for a while. I was about to attempt to port the layout to choc switches but it would seem a fresh commit's been made. Is this a finished layout and has it been tested?

Most kind of you to share what you create! Please share if any help is needed.

/ Jona

jpconstantineau, 2018-10-17:
No. It's not been produced or tested yet.  There are already some
modifications I need to make to the PCB.

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

jpconstantineau, 2018-10-25:
@Cwejman if you are interested in the chocolate switches layout, what features would you also be interested in? I am considering adding smd LEDs (either rgb or not).

mattkelly, 2019-03-03:
@jpconstantineau I'm also interested in trying out the choc layout. Any hints as to what PCB modifications are already known to be needed? I'm not interested in LEDs or other features (well, maybe Bluetooth at some point) - mostly just the switches themselves for a lower profile.

jpconstantineau, 2019-03-03:
I do have prototype PCBs on hand and am looking to sell them.  My latest
working  ErgoTravel is the choc version and being much thinner (and ble
too) it's an ideal travel keyboard.  Email me at jpconstantineau@gmail.
It's on the list of extras I have post GB.

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

themmes, 2019-04-04:
@jpconstantineau are these the one you dubbed ErgoTravelLight on the Githubpage?

jpconstantineau, 2019-04-04:
Yes. I do have some on hand if you are interested.

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
--
Pierre

themmes, 2019-04-04:
With some, you mean PCBs? Very cool! Would these also work with the new Kailh X type switches?

jpconstantineau, 2019-04-04:
Humm  Good question about those new switches.  The footprint is not the
same and the plate cutout is similar.

Both switches uses a 14mmx14mm switch plate cutout.  The locations of the
pins is different.
The choc switch has a hole for a LED.  The X doesnt.

By comparing the drawings here:
http://www.kailh.com/en/Products/Ks/NotebookS/649.html
and here: http://www.kailh.com/en/Products/Ks/CS/319.html
Looks like the PCB would need to be updated to support those.

Getting the switches and compatible keycaps would be the harder part....

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

--
Pierre

themmes, 2019-04-04:
I thought I read somewhere that the X has LED built in? Well, I am not too interested in backlight for now anyways..

I think the X Switch can be ordered here; https://nl.aliexpress.com/store/product/Kaih-Low-profile-Notebook-X-Switch-keyboard-switch-for-laptop-tactil-type-Pretravel-1-2mm-clikcy/4670072_32985602923.html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

Hmm.. I am not familiar with drawing PCBs but I could give it a try. I saw you were using KiCAD software? Are there any other parts I should adapt that you know of?

jpconstantineau, 2019-04-04:
looking at the picture of the switch itself on aliexpress, there is a
cutout at the bottom of the switch for a LED.

They are not cheap at 1.30USD/switch...  Keycaps available from Kailh are a
bit boring... blank whites...
For an ErgoTravelThin (?) you would need 6 packs of 10 switches and 2 packs
of 50 keycaps.  For a total of 107USD. That's almost twice the price of
choc switches...

You would need to use Kicad:
1 - create the switch footprint in the footprint editor
2 - replace the mapping between schematic and PCB for the switches to point
to new footprint
3 - export NET
4 - Go to PCB editor
5 - import NET, replace footprints
6 - re-route all wires
7 - run design check/pour copper planes
8 - create Gerber
9 - send gerber to PCB fab.

Perhaps someone already has the X switches footprint - done in a reversible
way (we need it to be reversible since we flip the PCB upside down for the
left/right halves)

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

--
Pierre

themmes, 2019-04-04:
Thanks for this extensive overview! I agree that these are very expensive switches.

If using the Kailh Choc switches, what do you have laying around that I could buy? PCB or PCB with casing or full kit?

jpconstantineau, 2019-04-04:
Email me at jpconstantineau@gmail and we can continue offline... I have
full kits

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
--
Pierre

Closed 2021-11-24.

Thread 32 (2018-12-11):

Question: Partially assembled ErgoTravel ProMicro attachment

berfarah, 2018-12-11:
Hiya! Please let me know if you prefer that questions be in a thread on reddit, I'm happy to oblige and move this to wherever makes sense.

I opted for the partially built keyboard, which means that the diodes and Pro Micro headers were already on the board (thank you).

Looking at the guide, it looks like you solder diode pins to the pro-micro rather than the header pins I got. I got header pins in my kit and I just want to verify before I goof up my build:
- Are header pins intended to be soldered onto the pro micro / do they fit into the pro-micro headers?
- Should I get and use diode legs instead?

I tested individual header pins and it doesn't seem like they stick in the sockets, though I could just not be trying hard enough.

jpconstantineau, 2018-12-11:
Headers won't fit in the sockets.

For wires, you can use diode legs or any wire that's thin enough to fit
securely in the sockets.

24awg or 26awg wire should work well with the sockets. Anything bigger and
you will have trouble removing the pro micro. Anything thinner and you may
have intermittent connections.

The two types of sockets I have used have slightly different diameters and
the 24awg is on the larger side for the low profile sockets but work well
for the tall sockets.

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

berfarah, 2018-12-11:
@jpconstantineau awesome, thanks! That answers the question, I'll close this issue.

Closed 2018-12-11.

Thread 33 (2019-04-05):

Acrylic Case Path Lengths and Thickness

sedgwickc, 2019-04-05:
I'm looking to have an acrylic/steel combo case cut for an ErgoTravel build but I have some questions about the case files in the repo:

1. Are the files in acryliccase/jpconstantineau/ compatible with the middle section defined in the grogdor folder?

2. What are the dimensions and path lengths for the top1u1u, middle and bottom plates defined in the grogdor folder (or is there some way to determine these values from the svg files provided)?

3. What thickness of acrylic should be used when getting the middle section cut (assuming the top and bottom are both acrylic)?

jpconstantineau, 2019-04-05:
1 - files in  acryliccase/jpconstantineau/ should not be relied upon.  In
fact, they should be removed since they have not been used for production
2 - I don't know about this. Gorgdor did all the work on the laser cutter
he has access at his maker space.
3 - we used a stack of 4 3mm sheets for the middle sections.  the same 3mm
as the top/bottom plates.

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

--
Pierre

sedgwickc, 2019-04-05:
Thanks for the response @jpconstantineau! So it sounds like I should be using @Grogdor's version of the case files then. I was planning to go with a thinner top plate since the stainless steel will be strong enough at the same thickness as the PCB plates to serve its purpose so I'm glad that you mentioned that.

@Grogdor: are you able to provide the path length and dimensions for the 1u1u top plate, middle sections and bottom plate (or the .dxf files that contain information)?

Grogdor, 2019-04-07:
Hello,

1) I'll submit a PR to sync the production files from my repo, but be warned they're a mess. There's the regular wired version, another for Bluemicro, remnants of "tented" designs which were never used, and various DFM iterations.
2) Use my DXFs with your workflow. They're metric and generally sane, may want to "overkill" them and verify polylines, dimensions.
3) Check out the pics/ for stackup, a single 12mm layer of acrylic would be nicest/strongest. If I recall, you can get away with 9mm for low-profile headerless Arduino mounting, and possibly Bluemicro. We used multiple 3mm layers for stackup flexibility, ease of manufacturing and cost.

For your metal top plate, use switch spec of 1.5mm plate thickness and remove the engrave (black box) near the 2u thumb switch. Beware I found some extra red cut lines inserted around the engrave when importing/printing this to the laser cutter, so verify the measurements because dxf fills seem to get mangled. Are you cutting yourself, or sending this off? Appreciate any feedback, and pics of the result.

sedgwickc, 2019-04-15:
Thanks @Grogdor for the PR, your files are exactly what I needed! I have made a version of the "top only bluemicro DFM9.dxf" file using LibreCAD that is missing the stab engrave as well as cutlines and the measurements still look sane. I submitted it to LaserBoost for cutting from stainless steel at 1.5mm. I'll update with the result and pictures once the plates arrive.

jpconstantineau, 2019-04-15:
Sounds great!

Once you get your plates and validate that it's all good, you could add
your cad files to the repo. This way, the next person who would want metal
plates, would be able to start from your files.

Looking forward to pictures...

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
--
Pierre

sedgwickc, 2019-05-19:
The plates have arrived! I don't have any bottom plates yet so I can't confirm that the top plate holes will match up but the switch holes line up nicely so I'm not too worried. I'll clean up my local repo then submit a pull request soon with the pictures and design files. Here are some pictures with the plate and PCB held together with some switches which aren't soldered in place:

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

jpconstantineau, 2019-05-19:
These look great. I'll approve the PR when I get it.

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

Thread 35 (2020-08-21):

V1.03 gerber not recognised by JLCPB

Daveyr, 2020-08-21:
The V1.03 pcb gerber is not recognised by JLCPCB. It cannot detect dimensions or give a visual preview of the board. This makes me concerned that the gerber may be defective and so I am hesitant to order.

Please can you take a look?

Daveyr, 2020-09-06:
I replotted gerbers from the pcb folder, using the option to merge drill files when generating them. This seems to have solved the rendering problem. Would gerbers plotted from the /pcb folder of the `master` branch be identical to that found in GerberFiles/V1.03_Final/PCB.103b.Gerber.zip ?

If so, I'm happy to edit and submit a pull request once I've verified the physical board works.

Ardakilic, 2021-06-27:
Hello, I'm experiencing same issue.

What do I have to provide for dimensions ? Or how do I merge the drill paths ?

@Daveyr I'd love to have your modified gerber files by the way.

jpconstantineau, 2021-06-27:
I have produced hundred of boards at JLC with this zipped gerber (1.03).
You do need to enter the dimensions in the quotation tool and it works fine from that. You can use the same dimensions as the internal screws bottom plate.

Ardakilic, 2021-06-27:
Hey there, awesome! Thank you! I'll proceed just like that.

jpconstantineau, 2021-06-27:
If you want to have a detailed look at the gerber, you can use this viewer: https://tracespace.io/view/

Daveyr, 2021-06-30:
btw, I never did send off to JLCPCB to make the circuits but I from memory I did manage to make the preview work. On the JLCPCB website there's a guide on using the right settings for drill paths, which I followed and I think merged them with the gerbers. If I have time I can see whether my branch is clean enough to merge but it would be unverified as I never actually had them made.

Ardakilic, 2021-07-01:
This is what JLCPCB just asked me:

> By merging the 2 drill files, do you confirm that they are all plated? Otherwise we shall fabricate as plated and non-plated drills separately.

How should I respond them as ? Sorry I don't know much about drill plating.

Ardakilic, 2021-07-01:
By checking the PCB design, I'll be responding them as one of the drills (soldering holes) will be plated, the another (mounting holes) will be not, along with some PCB photos for them as referrence.

I hope what I'm going to tell is correct.

jpconstantineau, 2021-07-01:
Mounting holes should not be plated and other holes should be plated,
including the switch ones.  This is the first time I hear them ask about
this. Simply tell them to produce as is and it should come out fine. I have
had them make several hundred of these boards over the last few years
without them asking anything.

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

Ardakilic, 2021-07-01:
@jpconstantineau sorry to bother but can you please confirm? In this photo, all the blues have to be plated, and oranges should not be plated, right?

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

jpconstantineau, 2021-07-01:
That's correct. I forgot about the switch mounting holes.

All of what you indicated is correct. There are mounting holes for the
standoffs, the switches, tres connector and even the stabilizer.

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

Ardakilic, 2021-07-01:
Thank you for the clarification!
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

This was the exact area where confused me, but I'll just tell them to proceed like I mentioned.

Thanks once again!

Ardakilic, 2021-07-13:
The PCBs have arrived! Here's what I received from JLCPCB.

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

Also, they have corrected my dimension input like this:

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

If I recall correctly I had provided the bottom plate's dimensions (I also got bottom and plate printed, they have the same dimensions)

On the first glance, the PCB traces look nice, but I wanted to share for reference.

I'll be building in the following days.

Thanks again for the ongoing support and making this keyboard open-sourced! 🎉

Ardakilic, 2021-07-28:
Hello, I can confirm I have built the Ergotravel without issues ! 🎉

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

Apologies for the potato quality photo. I suck at taking photos.

I have already socketed the pro micro, and I will try Nice!Nano v2 with ZMK (shield does not exist on the codebase yet). If I succeed I'll try to create a pull request to ZMK repository.

Thank you for extended support! It's highly appreciated!

Closed 2021-11-24.

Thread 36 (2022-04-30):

Some questions about ErgoTravelLight 3.01

Ardakilic, 2022-04-30:
Hello,

First of all, thanks for making this board available for us all! I loved the Cherry MX variant and printed a choc variant, but I have some questions.

I printed ErgoTravelLight v3.01 by/for myself without even checking #29 (I built the cherry version back then and I wanted to make a choc variant), while ordering other stuff from JLCPCB, and I'm currently a bit confused:

Is this version even checked and confirmed working? I received the boards this week from JLC and when I check now I'm a bit confused. Are there any guides available ?

1. Are the orientation of Pro micros same with Cherry variant, as in build guide?
2. What is the diodes' orientation? I cannot discriminate it on the PCB silk screen. Any photos available to check ? Or, Is the diodes' orientation same as the Cherry MX guide, where the zener diodes' black lines are in same orientation as SMD ones' vertical lines?
3. Which LEDs would you prefer for soldering ? I have ws2812b 3535, but I believe it'd be impossible to solder these with iron, so cream flux + heat would be required since the foot print is too small.

Thanks in advance!

jpconstantineau, 2022-04-30:
RGB LEDs: SK6812-EC1515
These are 1.5mm x 1.5mm to be able to fit in the hole of the switch.  They are very small and quite difficult to install. As you indicated, there is no clear indication of the polarity on how to install them. LEDs are installed on the same side as thee switches.

Zener diodes: There aren't any zeners. They should be standard 1N4148 in the surface mount type - do not use through-hole diodes as these will cause problems with the top plate.  As for their orientation, I believe there is a larger band but would have to double check on the actual PCB.  I do have a set assembled here, I could take pictures and attach here. Diodes should be installed the other side from the switches.

Pro Micros: most robust way to check the orientation is with a multimeter. The pro micro has 2 GND pins next to each other on one side and this should match what's on the board.  They get installed on the same side as the diodes, opposite side to the switches.  Remember to use sockets or make sure not to solder them in the wrong sequence (or you won't be able to install  the switches)

There aren't any build guides for this one and I only build a set.  It's best to get the circuit diagram printed as there are a few components that might need a bit of clarity on where they go, how they are connected and what values are needed.

Ardakilic, 2022-05-01:
Hello again,

Regarding the diodes; I was mentioning about the polarity of them. Since I believe the orientation is same with the cherry one's zener diodes, which are shown in the build guide pictures, I was asking whether the polarity and orientation is same with the one on the guide. I'll use 1n4148 sod-123 diodes. If the position of the black lines on the zener diodes, which is shown on the build guide, match with the lines of the SMD diode chips, it's okay. If not, I'd love to take a look at them, if it wouldn't be a bother to you. Or at least the photo of the PCB/screenshot of the PCB design with silk screen that indicates the diodes' positions would be great.

Regarding the pro micros. Thanks! I'll use sockets, and just did not want to burn them if I made something stupid, since they are becoming way more expensive due to chip shortage.

Thanks! I'll also try to check with the circuit diagram if I'm stuck. I hope everything goes well.

jpconstantineau, 2022-05-01:
I'll get a few pictures.

The diodes for the regular ergotravel, they are just small switching diodes of the type 1n4148 package DO35.  Zener diodes are used for something completely different.  They have a specifically designed reverse voltage at which they will conduct in reverse.  They are used as voltage references or in low-efficiency voltage regulation applications.  Zener diodes are not used for keyboards.  The Ergotravel build pictures show a glass DO35 package small signal diode, not a zener diode.  They might look the same, however, their behavior is quite different.

My standard surface mount diodes are of SOD-123 package.  I'll get a few pictures included here later tonight.

jpconstantineau, 2022-05-01:
Top View - Board Boards
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

Bottom View - Both boards
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

Surface Mount Diode. Note position of Bar on Diode lines up with bounding box/line on silkscreen
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

Position of RGB LED (Note black dot at top right)
Also note orientation of RAW pin of Pro Micro
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

Position of RGB LED (Note absence of black dot at top right) - other half
Also note orientation of RAW pin of Pro Micro
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

Note that for the RGB LEDs to be powered on and to receive their data, a few 0-ohm resistors need  to be installed.  See below:
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

Ardakilic, 2022-05-01:
Hello again,

Thanks for these. Seriously! This will help a lot! 🙏

Here's what JLCPCB sent me:

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

I believe JLC messed up my silk screens. I don't have these indicator line between two other lines on diodes.

What value are these caps btw? Would 100nf work ?

Also, can you confirm please? If I skip the LEDs, I won't need 0ohm resistors and the caps, correct ?

Thanks again for the effort!

Ardakilic, 2022-05-03:
I have soldered diodes, TRRS connector and pro micro sockets. When pro micros and switches arrive I'll try to test whether it's working as expected or not.

Ardakilic, 2022-08-01:
Hey @jpconstantineau , apologies foe the huge delay. I changed my job, and renovated my house, so the delay happened.

Here's what I achieved so far:

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

This is currently working as a split keyboard with a TRRS cable. I have just not decided how should I fit the bottom.

I could not use top plate, because the pro micro connector/socket's solder joints' height makes the top plate not fit between board and switch. It needs to be thinner than 1.6mm. The worst part is JLCPCB asked for $15 more because it had "too many holes", apart from the $9.3 initial price. The thin edges may be the reason for this.

I could not solder these RGB LEDs, so that's why I did not solder any caps. I even fail mostly at while soldering WS2812B 5050 LEDs. The smallest component that I can solder by hand is 0603 components. I say these LEDs are almost impossible to solder by hand, at least for me.

I'll try LED strips in the future, I had tried that on Cherry MX version last year and it worked great.

Thanks again for making this available!

Ardakilic, 2022-08-04:
I'm closing this issue because there's nothing left of me for to ask. As mentioned, maybe the choc version's plate can be cheaper, apart from that everything works as expected. Thanks once again!

jpconstantineau, 2022-10-11:
I see, JLC des have the tendency to edit gerbers before they send them to
production.
If you load the gerber on this site, you should be able to see all the
details.
https://tracespace.io/view/

Without RGB LEDs, you don't need these 0 ohm resistors or the capacitors.

On Sun, May 1, 2022 at 11:28 AM Arda Kılıçdağı ***@***.***>
wrote:

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

--
Pierre

Closed 2022-08-04.

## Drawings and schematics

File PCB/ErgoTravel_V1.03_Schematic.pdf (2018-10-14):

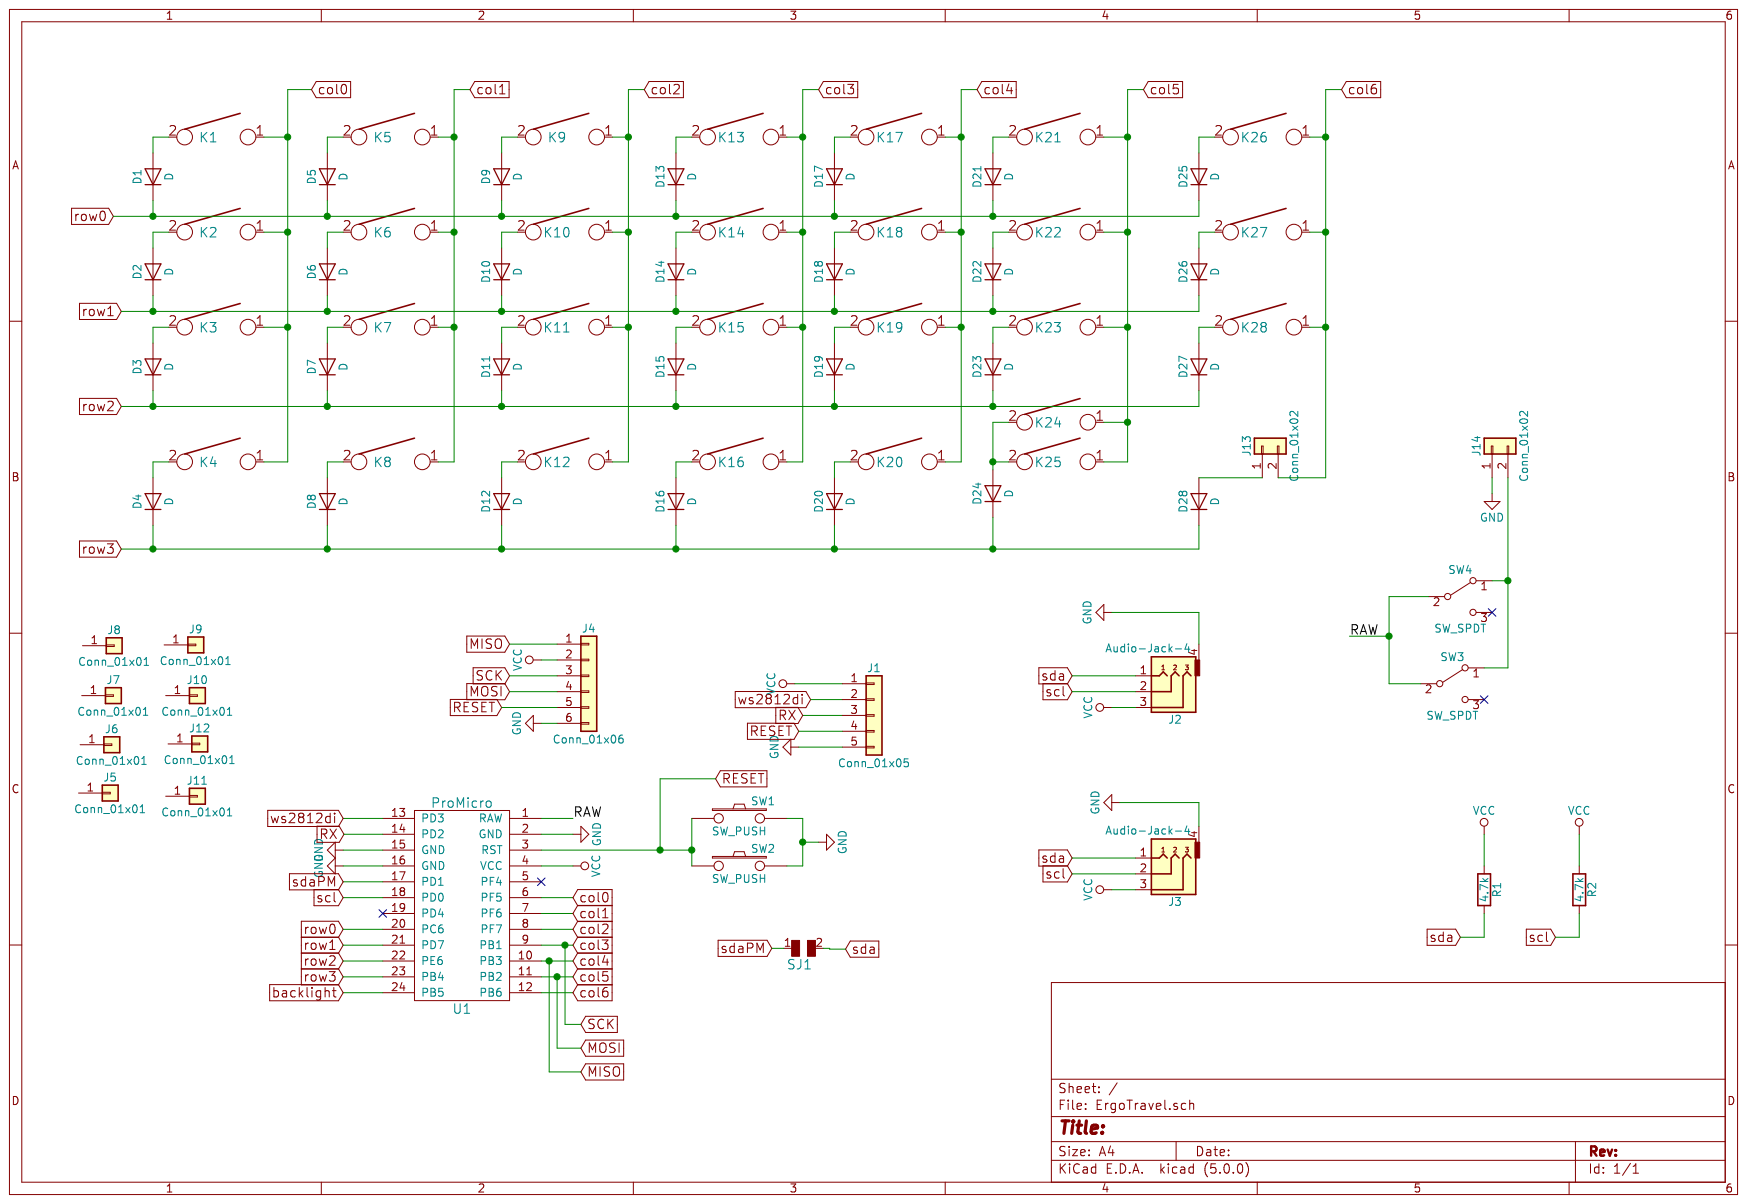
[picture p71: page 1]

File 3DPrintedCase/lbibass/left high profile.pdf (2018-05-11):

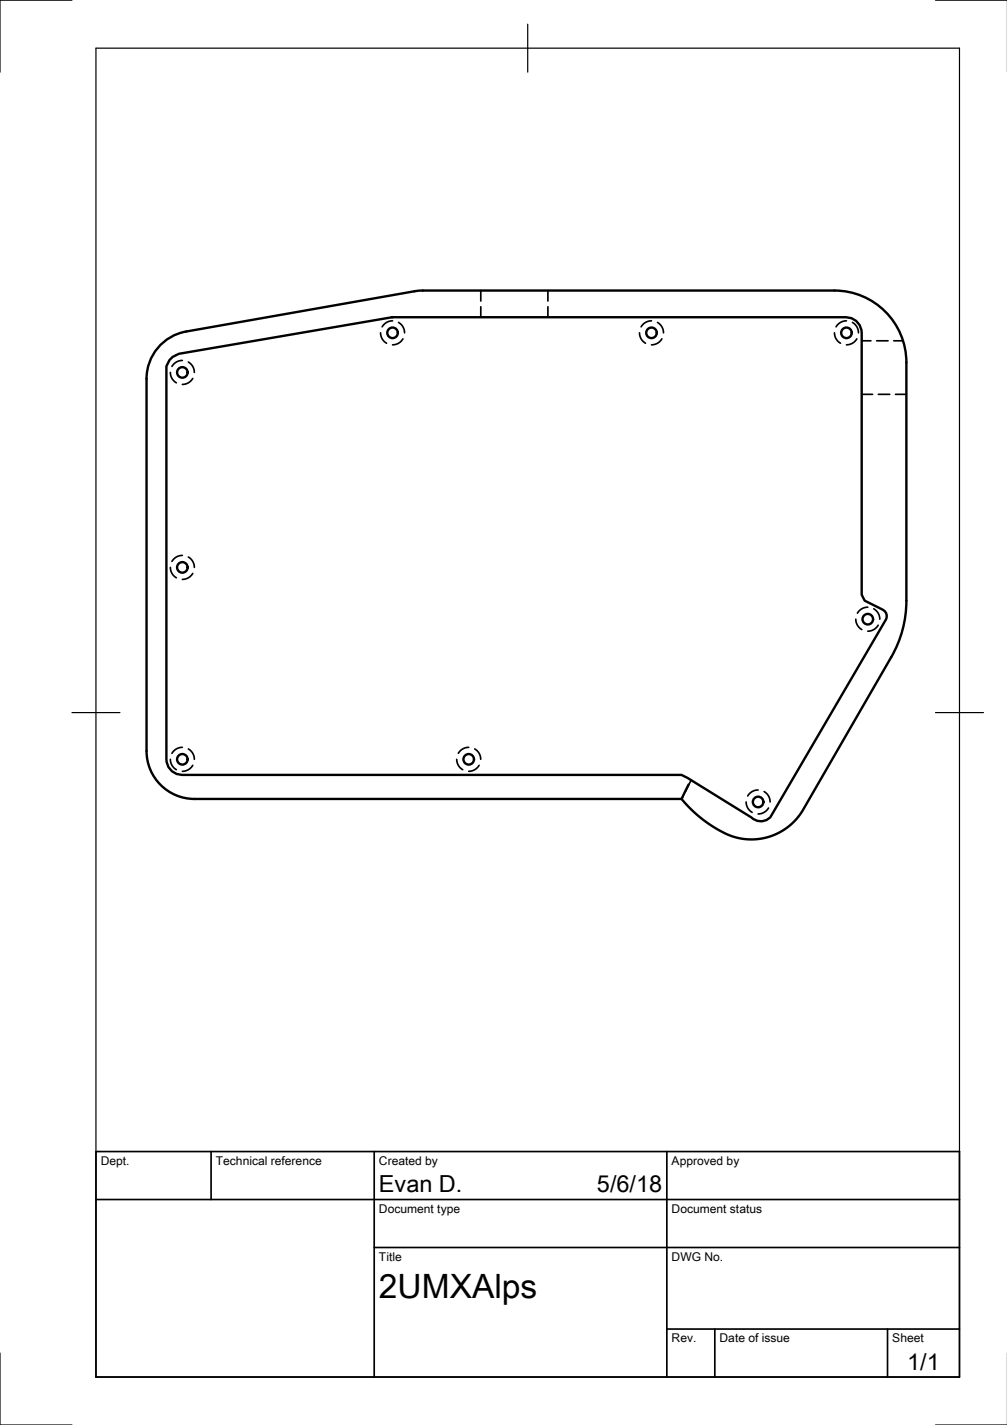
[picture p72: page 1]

Dept. | Technical reference | Created by Evan D. 5/6/18 | Approved by

Document type | Document status

Title 2UMXAlps | DWG No.

Rev. | Date of issue | Sheet 1/1

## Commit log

2018-03-09 Adding BOM
2018-03-09 CHanging BOM to Tables
2018-03-09 CHanging BOM Tables
2018-03-09 CHanging BOM Tables again
2018-03-09 CHanging BOM Tables yet again
2018-03-10 CHanging all BOM Tables now that tables work
2018-03-10 Fixing BOM table
2018-03-20 adding 3d printed case, reorg of gerber folders
    [ErgoTravel.kicad_pcb]
2018-03-21 editing Build Instructions - Tabular switch config
2018-03-21 adding diode image
2018-03-21 Updated to V1.01
    [ErgoTravel-B.Cu.gbr, ErgoTravel-B.Mask.gbr, ErgoTravel-B.SilkS.gbr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]
2018-03-27 Adding internal Plates
    [1UMX.dxf, 1UMXApls.dxf, 2UMX.dxf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]
2018-03-27 Added Comments on Standoffs
2018-03-30 updated build log and added additional images of diode installation
2018-03-30 add instructions for soldering the diodes.
2018-03-30 moved D13
    [ErgoTravel.kicad_pcb, ErgoTravel.sch]
2018-03-30 update diodes photo with higher quality photo
2018-03-30 crop diode image
2018-03-30 updated instructions with higher quality pictures for reset switch and trrs connector
2018-03-30 added instructions and images for soldering sockets
2018-03-30 added pictures of pcbs after all components have been installed
2018-03-31 finish up pro micro installation using sockets
2018-04-04 switch soldering instructions
2018-04-12 V1.01 PCB and Plates incl Gerbers
    [Bottom Plate.kicad_pcb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]
2018-04-29 adding dfx file for external Top Plate
    [Top Plate-Edge.Cuts.dxf, Top Plate.kicad_pcb]
2018-04-29 adding more dfx files for external Top Plate
    [Top Plate-B.Cu.dxf, Top Plate-B.SilkS.dxf, Top Plate-F.Cu.dxf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]
2018-04-29 adding svg export files for external Top Plate
2018-05-06 Added 3D Printed Cases.
    you have the option of high profile and low profile.
    [Bottom Plate-B.Cu.dxf, Bottom Plate-B.Mask.dxf, Bottom Plate-B.SilkS.dxf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]
2018-05-06 initial V1.02 files and 3d printed case folders
    [1UMX.dxf, 1UMXApls.dxf, 2UMX.dxf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]
2018-05-11 reorg of case files and adding gitignore
    [high_profile.stl, high_profile_left.stl, high_profile_right.stl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]
2018-05-28 Updating Internal Plates with Alps/MX Openings
    [Bottom Plate-B.Cu.dxf, Bottom Plate-B.Mask.dxf, Bottom Plate-B.SilkS.dxf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]
2018-05-28 updating Internal Plates Gerbers
    [Bottom Plate-B.Cu.gbr, Bottom Plate-B.Mask.gbr, Bottom Plate-B.SilkS.gbr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]
2018-06-02 adding RGB images
    [Bottom Plate-B.Cu.dxf, Bottom Plate-B.Mask.dxf, Bottom Plate-B.SilkS.dxf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]
2018-06-06 notes re: 2u hole
2018-06-18 Changing Adding priotities to Acrylic Case items
    [ErgoTravel-B.Cu.gbr, ErgoTravel-B.Mask.gbr, ErgoTravel-B.SilkS.gbr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]
2018-06-19 adding internal screws case instructions
2018-06-27 switchplate fixes
    [everything.dxf]
2018-06-27 rainbow'ed switchplate cutlines and slow edges
    Attempting to spread out the hot laser action so acrylic gasses don't ignite and *thump* under the plate, causing material to jump. For a smoother edge finish, slow down red cuts and turn off air ass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
    [everything.dxf]
2018-06-27 remove SVGs
    Not generating SVGs through Inkscape anymore, now printing DXF straight from Corel Draw
2018-06-27 tenting and cutting tweaks
    [everything.dxf]
2018-06-27 reorder layer colors
    [everything.dxf]
2018-06-27 internal/hipro/bluemicro plates
    [everything.dxf]
2018-06-27 new hipro, nudge internal screwholes
    [everything.dxf]
2018-06-28 nudge holes
    [everything.dxf]
2018-10-11 last Kicad4.7 commit
    [Bottom Plate-B.Cu.gbr, Bottom Plate-B.Mask.gbr, Bottom Plate-B.SilkS.gbr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]
2018-10-11 first Kicad 5.0 commit
    [ErgoTravel-2018-10-05-16-46-11.sch, ErgoTravel-2018-10-06-13-02-23.sch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]
2018-10-11 adding images for Internal Screw Case
2018-10-11 adding TRRS Glueing image to build instructions
2018-10-11 Updated Acrylic Case List
2018-10-11 making minor changes to account for acrylic plates.
2018-10-14 Adding schematic
2018-10-15 mess of DFM8
    files from first production batch, plated for bucked material, small two pieces for scrap, HiPro corrections
    [bottoms only DFM8.dxf, everything DFM8.dxf, everything nite.dxf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]
2018-11-06 bluemicro edition
    "TENTED" is all wrong do not use, everything is a bit of a mess, but bluemicros are cranking out
    [bottoms only bluemicro DFM9.dxf, everything (2).dxf, everything DFM9.dxf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]
2018-11-06 separate outside top hipro for cutline ordering
    [everything DFM9.dxf]
2018-11-17 add Alps switch considerations
2019-11-09 updated to choc with LEDs (more to come)
    [ErgoTravel-2018-10-06-13-02-23.sch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]
2019-11-10 adding 3d model in openscad for acrylic mids with ergodox legs
    [#mids only DFM8.dxf, 3dmids.scad, mids only DFM8.dxf]
2019-11-10 adding second leg position option
    [#mids only DFM8.dxf, 3dmids_back.scad]
2019-11-17 adding prototype for mids
    [3dmids_prototype.scad, 3dmids_prototype.stl, ErgoTravel-2018-10-06-13-02-23.sch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]
2019-11-17 splitting stl into 3 models
    [3dmids_prototype.scad, 3dmids_prototype_1.stl, 3dmids_prototype_2.stl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]
2021-10-27 added MX version (V1.1) to avoid extra JLCPCB fees
    [Bottom Plate-B.Cu.gbr, Bottom Plate-B.Mask.gbr, Bottom Plate-B.SilkS.gbr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]
